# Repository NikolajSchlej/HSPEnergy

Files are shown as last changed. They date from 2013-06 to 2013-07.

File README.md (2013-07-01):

HSP Energy
=========

Hardware project of HS Regensburg

This project of Embedded Systems Laboratory of HS Regensburg 
aims to work out rules and guidelines for energy-effective coding
for different uC families.

There is a base board, where DC-DC, JTAG debugger and USB-UART converter are located, 
and CPU boards for different microcontrollers.

Documentation will be added when ready.

Scematics and layouts made in EagleCAD 6. 
All hardware involved is open and available under terms of copyleft license.

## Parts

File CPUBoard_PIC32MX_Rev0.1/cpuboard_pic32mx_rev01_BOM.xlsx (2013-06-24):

Designator | Quantity | Designator | Value1 | Value2 | Value3 | Package | Description | Manufacturer | Manufacturer # | Farnell # | Digikey # | Unit price € | Total Price €
 | 1 |  |  |  |  | TQFP-100 | Microcontroller | Microchip | PIC32MX320F128L | 1523321 | PIC32MX320F128L-80I/PT | 6.670 | 6.670
 | 1 | C9 | 10uF | 50V | +/- 20% | SMT | Aluminum Electrolytic Capacitor | Panasonic | EEEFK1H100P | 1850117 |  | 0.269 | 0.269
 | 2 |  | 1x24 |  |  |  | pin header male |  |  | 1593425 |  | 0.671 | 1.342
 | 2 | C1,C2 | 22pF |  |  | 0805 | Capacitor |  |  | 1885437 |  | 0.297 | 0.594
 | 7 | C3,C4,C5,C6,C7,C8,C10 | 100nF |  |  | 0805 | Capacitor | Multicomp |  | 1759265 |  | 0.011 | 0.077
DNP | 1 | JP3 |  |  |  |  | Programming connector
 | 1 | JP4 | RJ12 |  |  |  | Programming connector |  |  | 3938359 |  | 1.180 | 1.180
 | 2 | R1,R2 | 10K | 1% |  | 0805 | Resistor |  |  | 1612522 |  | 0.032 | 0.064
 | 2 | S1,S2 |  |  |  |  | tactile switch | ALPS | SKHHBWA010 | 2056816 |  | 0.162 | 0.162

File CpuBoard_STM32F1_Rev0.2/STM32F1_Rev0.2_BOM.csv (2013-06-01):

Part | Value | Device | Package | Description | MPN | OC_FARNELL | OC_NEWARK | PACKAGE | SUPPLIER
C1 | 10nF | C-EUC0805K | C0805K | CAPACITOR, European symbol
C2 | 100nF | C-EUC0805K | C0805K | CAPACITOR, European symbol
C3 | 100nF | C-EUC0805K | C0805K | CAPACITOR, European symbol
C4 | 20pF | C-EUC0805K | C0805K | CAPACITOR, European symbol
C5 | 20pF | C-EUC0805K | C0805K | CAPACITOR, European symbol
C6 | 1uF | CPOL-EUB | PANASONIC_B | POLARIZED CAPACITOR, European symbol
C7 | 100nF | C-EUC0805K | C0805K | CAPACITOR, European symbol
C8 | 100nF | C-EUC0805K | C0805K | CAPACITOR, European symbol
C9 | 100nF | C-EUC0805K | C0805K | CAPACITOR, European symbol
C10 | 100nF | C-EUC0805K | C0805K | CAPACITOR, European symbol
C11 | 10uF | CPOL-EUB | PANASONIC_B | POLARIZED CAPACITOR, European symbol
C12 | 100nF | C-EUC0805K | C0805K | CAPACITOR, European symbol
C13 | 100nF | C-EUC0805K | C0805K | CAPACITOR, European symbol
JP1 |  | PINHD-1X24 | 1X24 | PIN HEADER
JP2 |  | PINHD-2X10 | 2X10 | PIN HEADER
JP3 |  | PINHD-1X24 | 1X24 | PIN HEADER
L1 | 470 Ohm@100MHz | INDUCTOR0805 | 0805 | Inductors
R1 | 10K | R-EU_R0805 | R0805 | RESISTOR, European symbol
R2 | 10K | R-EU_R0805 | R0805 | RESISTOR, European symbol
R3 | 10K | R-EU_R0805 | R0805 | RESISTOR, European symbol
R4 | 10K | R-EU_R0805 | R0805 | RESISTOR, European symbol
R5 | 10K | R-EU_R0805 | R0805 | RESISTOR, European symbol
R6 | 10K | R-EU_R0805 | R0805 | RESISTOR, European symbol
R7_F1 | 0 | R-EU_R0805 | R0805 | RESISTOR, European symbol
R7_F2 | 0 | R-EU_R0805 | R0805 | RESISTOR, European symbol
R8_F1 | 0 | R-EU_R0805 | R0805 | RESISTOR, European symbol
R8_F2 | 0 | R-EU_R0805 | R0805 | RESISTOR, European symbol
R9_F1 | 0 | R-EU_R0805 | R0805 | RESISTOR, European symbol
S1 | SWITCH_TH | SWITCH_TH | SWITCH_TROUGHHOLE
S2 | SWITCH_TH | SWITCH_TH | SWITCH_TROUGHHOLE
S3 | SS12SDXX | SS12SDXX | SS12SDXX
S4 | SS12SDXX | SS12SDXX | SS12SDXX
S5 | SWS004 | SWS004 | SMS-004 | SMD Dip Switch 4 pol.
U$1 | OSHW-LOGOS | OSHW-LOGOS | OSHW-LOGO-S | Open Source Hardware Logo This logo indicates the piece of hardware it is found on incorporates a OSHW license and/or adheres to the definition of open source hardware found here: http://freedomdefined.org/OSHW
U1 | STM32L152VBT6 | STM32L152VBT6 | QFP50P1600X1600X160-100N | Ultralow power ARM-based 32-bit MCU | STM32L152VBT6 | 2060948 | 65T3809 | LQFP-100 | STMICROELECTRONICS
Y1 | 8MHz | CRYSTALSMD | HC49UP | Various standard crystals. Proven footprints. Spark Fun Electronics SKU : COM-00534

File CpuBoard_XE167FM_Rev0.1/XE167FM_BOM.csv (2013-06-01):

Part | Value | Device | Package | Description
C1 | 100nF | CAP0603-CAP | 0603-CAP | Capacitor
C2 | 100nF | CAP0603-CAP | 0603-CAP | Capacitor
C3 | 100nF | CAP0603-CAP | 0603-CAP | Capacitor
C4 | 100nF | CAP0603-CAP | 0603-CAP | Capacitor
C5 | 100nF | CAP0603-CAP | 0603-CAP | Capacitor
C6 | 100nF | CAP0603-CAP | 0603-CAP | Capacitor
C7 | 100nF | CAP0603-CAP | 0603-CAP | Capacitor
C8 | 100nF | CAP0603-CAP | 0603-CAP | Capacitor
C9 | 680nF | CAP0603-CAP | 0603-CAP | Capacitor
C10 | 680nF | CAP0603-CAP | 0603-CAP | Capacitor
C11 | 680nF | CAP0603-CAP | 0603-CAP | Capacitor
C12 | 680nF | CAP0603-CAP | 0603-CAP | Capacitor
C13 | 220nF | CAP0603-CAP | 0603-CAP | Capacitor
C14 | 1.2uF | CAP0603-CAP | 0603-CAP | Capacitor
C15 | 100nF | CAP0603-CAP | 0603-CAP | Capacitor
C16 | 18pF | CAP0603-CAP | 0603-CAP | Capacitor
C17 | 18pF | CAP0603-CAP | 0603-CAP | Capacitor
C18 | 100nF | CAP0603-CAP | 0603-CAP | Capacitor
CONF0 |  | SWITCH-SPDTPTH | SWITCH-SPDT | SPDT Switch
CONF1 |  | SWITCH-SPDTPTH | SWITCH-SPDT | SPDT Switch
CONF2 |  | SWITCH-SPDTPTH | SWITCH-SPDT | SPDT Switch
IC1 | XE167FM | XE167FM | LQFP144 | Infineon XE167FM
JP2 |  | PINHD-1X24 | 1X24 | PIN HEADER
JP3 |  | PINHD-1X24 | 1X24 | PIN HEADER
L1 | 470uH@100Mhz | INDUCTOR0603 | 0603 | Inductors
L2 | 470uH@100Mhz | INDUCTOR0603 | 0603 | Inductors
L3 | 470uH@100Mhz | INDUCTOR0603 | 0603 | Inductors
L4 | 470uH@100Mhz | INDUCTOR0603 | 0603 | Inductors
OCDS |  | PINHD-2X8_2.54 | 2X08 | PIN HEADER
R1 | 10K | RESISTOR0603-RES | 0603-RES | Resistor
R2 | 10K | RESISTOR0603-RES | 0603-RES | Resistor
R3 | 10K | RESISTOR0603-RES | 0603-RES | Resistor
R4 | 10K | RESISTOR0603-RES | 0603-RES | Resistor
R5 | 10K | RESISTOR0603-RES | 0603-RES | Resistor
RESET |  | TAC_SWITCHPTH | TACTILE-PTH | Momentary Switch
TRST |  | SWITCH-SPDTPTH | SWITCH-SPDT | SPDT Switch
VAGND |  | JP1E | JP1 | JUMPER
VAREF |  | JP1E | JP1 | JUMPER
Y1 | 8Mhz | CRYSTALSMD | HC49UP | Various standard crystals. Proven footprints. Spark Fun Electronics SKU : COM-00534

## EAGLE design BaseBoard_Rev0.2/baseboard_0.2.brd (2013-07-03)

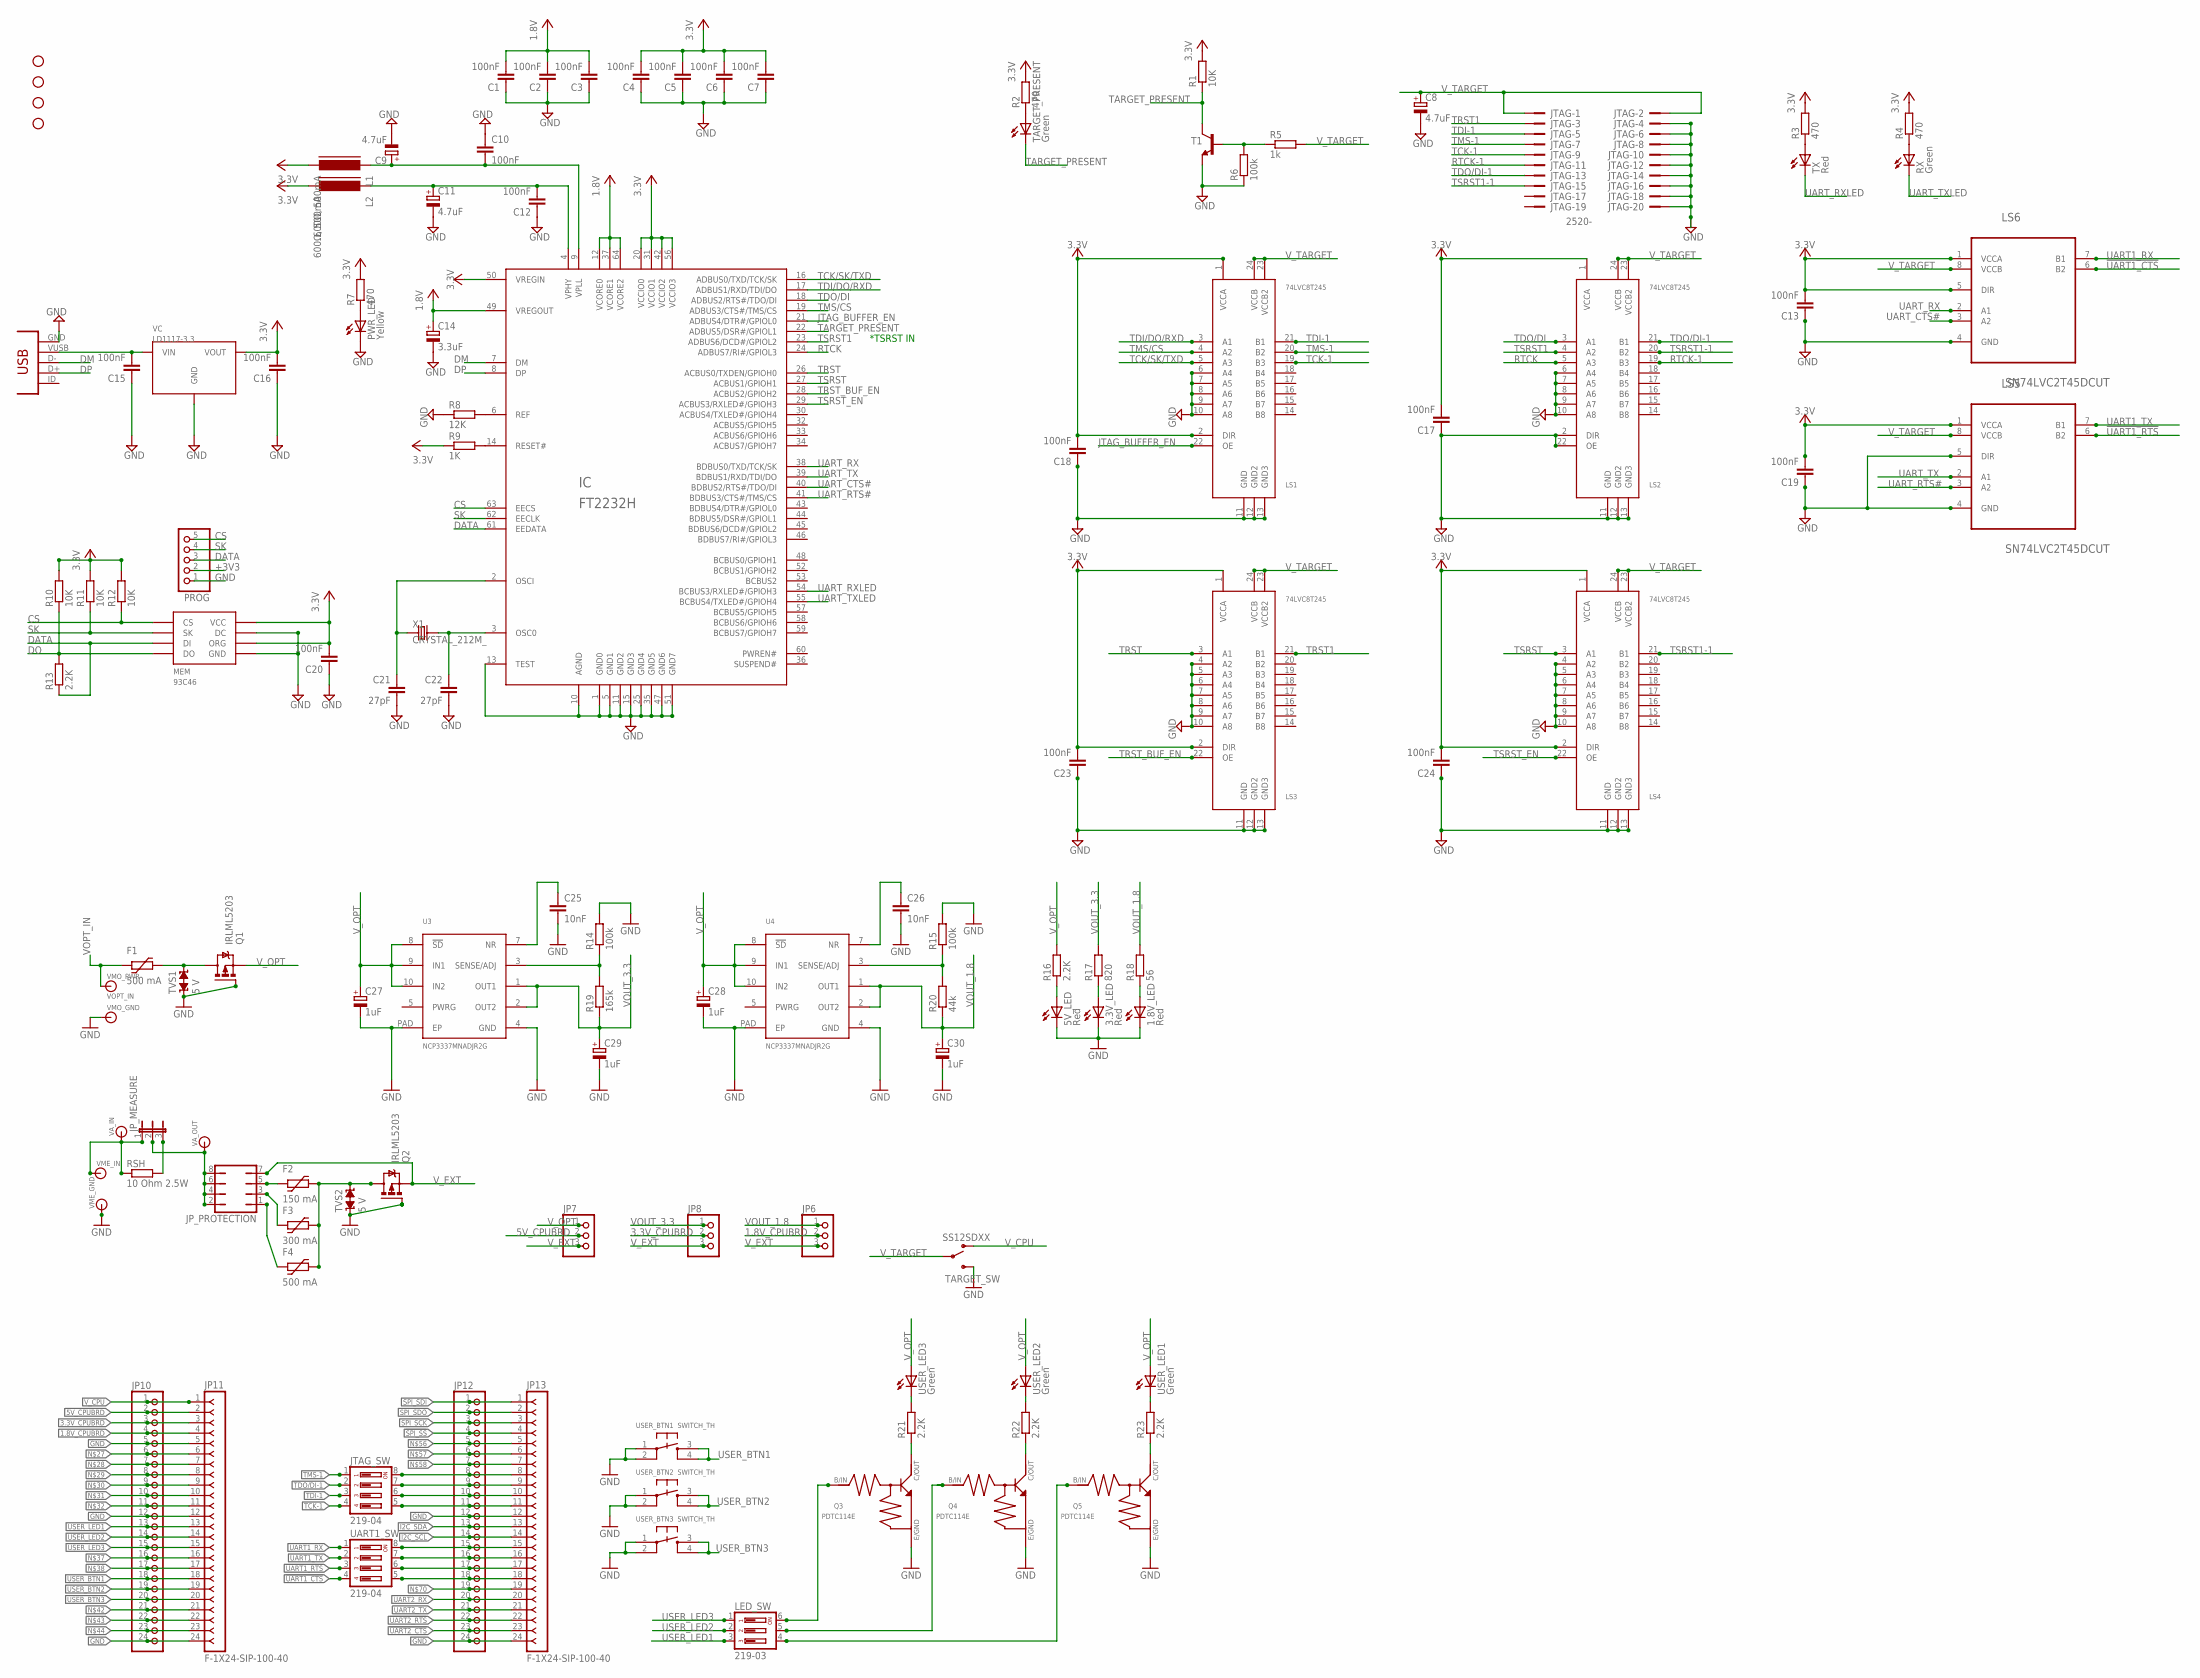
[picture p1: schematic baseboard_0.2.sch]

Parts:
1.8V_LED, 3.3V_LED, 5V_LED: Red; CHIPLED_0805
C1, C2, C3, C4, C5, C6, C7, C10, C12, C13, C15, C16, C17, C18, C19, C20, C23, C24: 100nF; C805
C8, C9, C11: 4.7uF; SMC_A
C14: 3.3uF; SMC_A
C21, C22: 27pF; C805
C25, C26: 10nF; C0805
C27, C28, C29, C30: 1uF; PANASONIC_B
CONN1: CONN_USB; CONN_USB_MINI-B
F1, F4: 500 mA; 1206L
F2: 150 mA; 1206L
F3: 300 mA; 1206L
IC: FT2232H; LQFP64
JP1, JP2, JP3, JP4: STAND-OFF
JP6, JP7, JP8: PINHD-1X3; 1X03
JP10, JP12: PINHD-1X24; 1X24
JP11, JP13: F-1X24-SIP-100-40; SIP-100-24-40
JP_MEASURE: JP2E; JP2
JP_PROTECTION: JP4Q
JTAG: 2520-; PAK100/2500-20
JTAG_SW: 219-04; CTS-219-04
L1, L2: 600Ω, 500mA; FB805
LED_SW: 219-03; CTS-219-03
LS1, LS2, LS3, LS4: 74LVC8T245; TSSOP24
LS5, LS6: SN74LVC2T45DCUT; SOP50P310X90-8N
MEM: 93C46; SOIC8
PROG: PINHD-1X5; 1X05
PWR_LED: Yellow; CHIPLED_0805
Q1, Q2: IRLML5203; MICRO3
Q3, Q4, Q5: PDTC114E; SOT416
R1, R10, R11, R12: 10K; R805
R2, R3, R4, R7: 470; R805
R5: 1k; R805
R6: 100k; R805
R8: 12K; R805
R9: 1K; R805
R13: 2.2K; R805
R14, R15: 100k; R0805
R16, R21, R22, R23: 2.2K; R0805
R17: 820; R0805
R18: 56; R0805
R19: 165k; R0805
R20: 44k; R0805
RSH: 10 Ohm 2.5W; R2512
RX: Green; CHIPLED_0805
T1: NPNSOT23BEC; SOT23-BEC
TARGET_PRESENT: Green; CHIPLED_0805
TARGET_SW: SS12SDXX
TVS1, TVS2: 5 V; TVS0805
TX: Red; CHIPLED_0805
U3, U4: NCP3337MNADJR2G; DFN10
UART1_SW: 219-04; CTS-219-04
USER_BTN1, USER_BTN2, USER_BTN3: SWITCH_TH; SWITCH_TROUGHHOLE
USER_LED1, USER_LED2, USER_LED3: Green; CHIPLED_0805
VA_IN: BANANA_CONN
VA_OUT: BANANA_CONN
VC: LD1117-3.3; SOT223
VME_GND: BANANA_CONN
VME_IN: BANANA_CONN
VMO_GND: BANANA_CONN
VMO_PWR: VOPT_IN; BANANA_CONN
X1: CRYSTAL_212M_; 4X6

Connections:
1.8V: C1.2, C2.2, C3.2, C14.+, IC.12 (VCORE0), IC.37 (VCORE1), IC.49 (VREGOUT), IC.64 (VCORE2)
1.8V_CPUBRD: JP6.2, JP10.4, JP11.4
3.3V_CPUBRD: JP8.2, JP10.3, JP11.3
5V_CPUBRD: JP7.2, JP10.2, JP11.2
!SPI_SS: JP12.4, JP13.4
!UART1_CTS: LS6.6 (B2), UART1_SW.4
!UART1_RTS: LS5.6 (B2), UART1_SW.3
!UART2_CTS: JP12.23, JP13.23
!UART2_RTS: JP12.22, JP13.22
+3V3: C4.2, C5.2, C6.2, C7.2, C13.2, C16.2, C17.2, C18.2, C19.2, C20.2, C23.2, C24.2, IC.20 (VCCIO0), IC.31 (VCCIO1), IC.42 (VCCIO2), IC.50 (VREGIN), IC.56 (VCCIO3), L1.2, L2.2, LS1.1 (VCCA), LS1.2 (DIR), LS2.1 (VCCA), LS3.1 (VCCA), LS3.2 (DIR), LS4.1 (VCCA), LS4.2 (DIR), LS5.1 (VCCA), LS6.1 (VCCA), LS6.5 (DIR), MEM.6 (ORG), MEM.8 (VCC), PROG.2, R1.2, R2.2, R3.2, R4.2, R7.2, R9.1, R10.2, R11.2, R12.2, VC.2 (VOUT)
CS: IC.63 (EECS), MEM.1 (CS), PROG.5, R12.1
DATA: IC.61 (EEDATA), MEM.3 (DI), PROG.3, R13.1
DM: CONN1.D-, IC.7 (DM)
DO: MEM.4 (DO), R10.1, R13.2
DP: CONN1.D+, IC.8 (DP)
GND: 1.8V_LED.C, 3.3V_LED.C, 5V_LED.C, C1.1, C2.1, C3.1, C4.1, C5.1, C6.1, C7.1, C8.-, C9.-, C10.1, C11.-, C12.1, C13.1, C14.-, C15.1, C16.1, C17.1, C18.1, C19.1, C20.1, C21.2, C22.2, C23.1, C24.1, C25.2, C26.2, C27.-, C28.-, C29.-, C30.-, CONN1.GND, IC.1 (GND0), IC.5 (GND1), IC.10 (AGND), IC.11 (GND2), IC.13 (TEST), IC.15 (GND3), IC.25 (GND4), IC.35 (GND5), IC.47 (GND6), IC.51 (GND7), JP10.5, JP10.12, JP10.24, JP11.5, JP11.12, JP11.24, JP12.12, JP12.24, JP13.12, JP13.24, JTAG.4, JTAG.6, JTAG.8, JTAG.10, JTAG.12, JTAG.14, JTAG.16, JTAG.18, JTAG.20, LS1.6 (A4), LS1.7 (A5), LS1.8 (A6), LS1.9 (A7), LS1.10 (A8), LS1.11 (GND), LS1.12 (GND2), LS1.13 (GND3), LS2.2 (DIR), LS2.6 (A4), LS2.7 (A5), LS2.8 (A6), LS2.9 (A7), LS2.10 (A8), LS2.11 (GND), LS2.12 (GND2), LS2.13 (GND3), LS2.22 (OE), LS3.4 (A2), LS3.5 (A3), LS3.6 (A4), LS3.7 (A5), LS3.8 (A6), LS3.9 (A7), LS3.10 (A8), LS3.11 (GND), LS3.12 (GND2), LS3.13 (GND3), LS4.4 (A2), LS4.5 (A3), LS4.6 (A4), LS4.7 (A5), LS4.8 (A6), LS4.9 (A7), LS4.10 (A8), LS4.11 (GND), LS4.12 (GND2), LS4.13 (GND3), LS5.4 (GND), LS5.5 (DIR), LS6.4 (GND), MEM.5 (GND), MEM.7 (DC), PROG.1, PWR_LED.C, Q1.1 (G), Q2.1 (G), Q3.2 (E), Q4.2 (E), Q5.2 (E), R6.1, R8.1, R14.2, R15.2, T1.E, TARGET_SW.3, TVS1.1, TVS2.1, U3.4 (GND), U3.PAD (EP), U4.4 (GND), U4.PAD (EP), USER_BTN1.1, USER_BTN1.2, USER_BTN2.1, USER_BTN2.2, USER_BTN3.1, USER_BTN3.2, VC.1 (GND), VME_GND.P$1, VMO_GND.P$1
I2C_SCL: JP12.14, JP13.14
I2C_SDA: JP12.13, JP13.13
JTAG_BUFFER_EN: IC.21 (ADBUS4/DTR#/GPIOL0), LS1.22 (OE)
JTAG_TCK: JP12.11, JP13.11, JTAG_SW.5
JTAG_TDI: JP12.10, JP13.10, JTAG_SW.6
JTAG_TDO: JP12.9, JP13.9, JTAG_SW.7
JTAG_TMS: JP12.8, JP13.8, JTAG_SW.8
unnamed: LED_SW.6, Q3.1 (B)
unnamed: C22.1, IC.3 (OSC0), X1.2 (X2)
unnamed: F2.P$1 (1), JP_PROTECTION.5
unnamed: F3.P$1 (1), JP_PROTECTION.3
unnamed: F4.P$1 (1), JP_PROTECTION.1
unnamed: F2.P$2 (2), F3.P$2 (2), F4.P$2 (2), Q2.3 (D), TVS2.2
unnamed: C21.1, IC.2 (OSCI), X1.1 (X1)
unnamed: C15.2, CONN1.VUSB, VC.3 (VIN)
unnamed: IC.14 (RESET#), R9.2
unnamed: IC.6 (REF), R8.2
unnamed: 3.3V_LED.A, R17.1
unnamed: R5.1, R6.2, T1.B
unnamed: PWR_LED.A, R7.1
unnamed: R2.1, TARGET_PRESENT.A
unnamed: F1.P$2 (2), Q1.3 (D), TVS1.2
unnamed: 5V_LED.A, R16.1
unnamed: R4.1, RX.A
unnamed: R3.1, TX.A
unnamed: LED_SW.4, Q5.1 (B)
unnamed: 1.8V_LED.A, R18.1
unnamed: JP10.6, JP11.6
unnamed: JP10.7, JP11.7
unnamed: JP10.8, JP11.8
unnamed: JP10.9, JP11.9
unnamed: JP10.10, JP11.10
unnamed: JP10.11, JP11.11
unnamed: JP_MEASURE.1, RSH.1, VA_IN.P$1, VME_IN.P$1
unnamed: JP_MEASURE.3, RSH.2
unnamed: JP10.16, JP11.16
unnamed: JP10.17, JP11.17
unnamed: JP10.21, JP11.21
unnamed: JP10.22, JP11.22
unnamed: JP10.23, JP11.23
unnamed: C25.1, U3.7 (NR)
unnamed: JP12.5, JP13.5
unnamed: JP12.6, JP13.6
unnamed: JP12.7, JP13.7
unnamed: Q3.3 (C), R21.1
unnamed: R21.2, USER_LED3.C
unnamed: R22.2, USER_LED2.C
unnamed: R23.2, USER_LED1.C
unnamed: Q4.3 (C), R22.1
unnamed: JP12.15, JP13.15, UART1_SW.8
unnamed: JP12.16, JP13.16, UART1_SW.7
unnamed: JP12.17, JP13.17, UART1_SW.6
unnamed: JP12.18, JP13.18, UART1_SW.5
unnamed: JP12.19, JP13.19
unnamed: R14.1, R19.2, U3.3 (SENSE/ADJ)
unnamed: Q5.3 (C), R23.1
unnamed: C26.1, U4.7 (NR)
unnamed: LED_SW.5, Q4.1 (B)
unnamed: R15.1, R20.2, U4.3 (SENSE/ADJ)
RTCK: IC.24 (ADBUS7/RI#/GPIOL3), LS2.5 (A3)
RTCK-1: JTAG.11, LS2.19 (B3)
SK: IC.62 (EECLK), MEM.2 (SK), PROG.4, R11.1
SPI_SCK: JP12.3, JP13.3
SPI_SDI: JP12.1, JP13.1
SPI_SDO: JP12.2, JP13.2
TARGET_PRESENT: IC.22 (ADBUS5/DSR#/GPIOL1), R1.1, T1.C, TARGET_PRESENT.C
TCK-1: JTAG.9, JTAG_SW.4, LS1.19 (B3)
TCK/SK/TXD: IC.16 (ADBUS0/TXD/TCK/SK), LS1.5 (A3)
TDI-1: JTAG.5, JTAG_SW.3, LS1.21 (B1)
TDI/DO/RXD: IC.17 (ADBUS1/RXD/TDI/DO), LS1.3 (A1)
TDO/DI: IC.18 (ADBUS2/RTS#/TDO/DI), LS2.3 (A1)
TDO/DI-1: JTAG.13, JTAG_SW.2, LS2.21 (B1)
TMS-1: JTAG.7, JTAG_SW.1, LS1.20 (B2)
TMS/CS: IC.19 (ADBUS3/CTS#/TMS/CS), LS1.4 (A2)
TRST: IC.26 (ACBUS0/TXDEN/GPIOH0), LS3.3 (A1)
TRST1: JTAG.3, LS3.21 (B1)
TRST_BUF_EN: IC.28 (ACBUS2/GPIOH2), LS3.22 (OE)
TSRST: IC.27 (ACBUS1/GPIOH1), LS4.3 (A1)
TSRST1: IC.23 (ADBUS6/DCD#/GPIOL2), LS2.4 (A2)
TSRST1-1: JTAG.15, LS2.20 (B2), LS4.21 (B1)
TSRST_EN: IC.29 (ACBUS3/RXLED#/GPIOH3), LS4.22 (OE)
UART1_RX: LS6.7 (B1), UART1_SW.1
UART1_TX: LS5.7 (B1), UART1_SW.2
UART2_RX: JP12.20, JP13.20
UART2_TX: JP12.21, JP13.21
UART_CTS#: IC.40 (BDBUS2/RTS#/TDO/DI), LS6.3 (A2)
UART_RTS#: IC.41 (BDBUS3/CTS#/TMS/CS), LS5.3 (A2)
UART_RX: IC.38 (BDBUS0/TXD/TCK/SK), LS6.2 (A1)
UART_RXLED: IC.54 (BCBUS3/RXLED#/GPIOH3), TX.C
UART_TX: IC.39 (BDBUS1/RXD/TDI/DO), LS5.2 (A1)
UART_TXLED: IC.55 (BCBUS4/TXLED#/GPIOH4), RX.C
USER_BTN1: JP10.18, JP11.18, USER_BTN1.3, USER_BTN1.4
USER_BTN2: JP10.19, JP11.19, USER_BTN2.3, USER_BTN2.4
USER_BTN3: JP10.20, JP11.20, USER_BTN3.3, USER_BTN3.4
USER_LED1: JP10.13, JP11.13, LED_SW.3
USER_LED2: JP10.14, JP11.14, LED_SW.2
USER_LED3: JP10.15, JP11.15, LED_SW.1
VEXT_IN: JP_MEASURE.2, JP_PROTECTION.2, JP_PROTECTION.4, JP_PROTECTION.6, JP_PROTECTION.8, VA_OUT.P$1
VOPT_IN: F1.P$1 (1), VMO_PWR.P$1
VOUT_1.8: C30.+, JP6.1, R18.2, R20.1, U4.1 (OUT1), U4.2 (OUT2)
VOUT_3.3: C29.+, JP8.1, R17.2, R19.1, U3.1 (OUT1), U3.2 (OUT2)
VPHY: C11.+, C12.2, IC.4 (VPHY), L2.1
VPLL: C9.+, C10.2, IC.9 (VPLL), L1.1
V_CPU: JP10.1, JP11.1, TARGET_SW.1
V_EXT: JP6.3, JP7.3, JP8.3, JP_PROTECTION.7, Q2.2 (S)
V_OPT: C27.+, C28.+, JP7.1, Q1.2 (S), R16.2, U3.8 (!SD), U3.9 (IN1), U3.10 (IN2), U4.8 (!SD), U4.9 (IN1), U4.10 (IN2), USER_LED1.A, USER_LED2.A, USER_LED3.A
V_TARGET: C8.+, JTAG.1, JTAG.2, LS1.23 (VCCB2), LS1.24 (VCCB), LS2.23 (VCCB2), LS2.24 (VCCB), LS3.23 (VCCB2), LS3.24 (VCCB), LS4.23 (VCCB2), LS4.24 (VCCB), LS5.8 (VCCB), LS6.8 (VCCB), R5.2, TARGET_SW.2

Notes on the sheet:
*TSRST IN

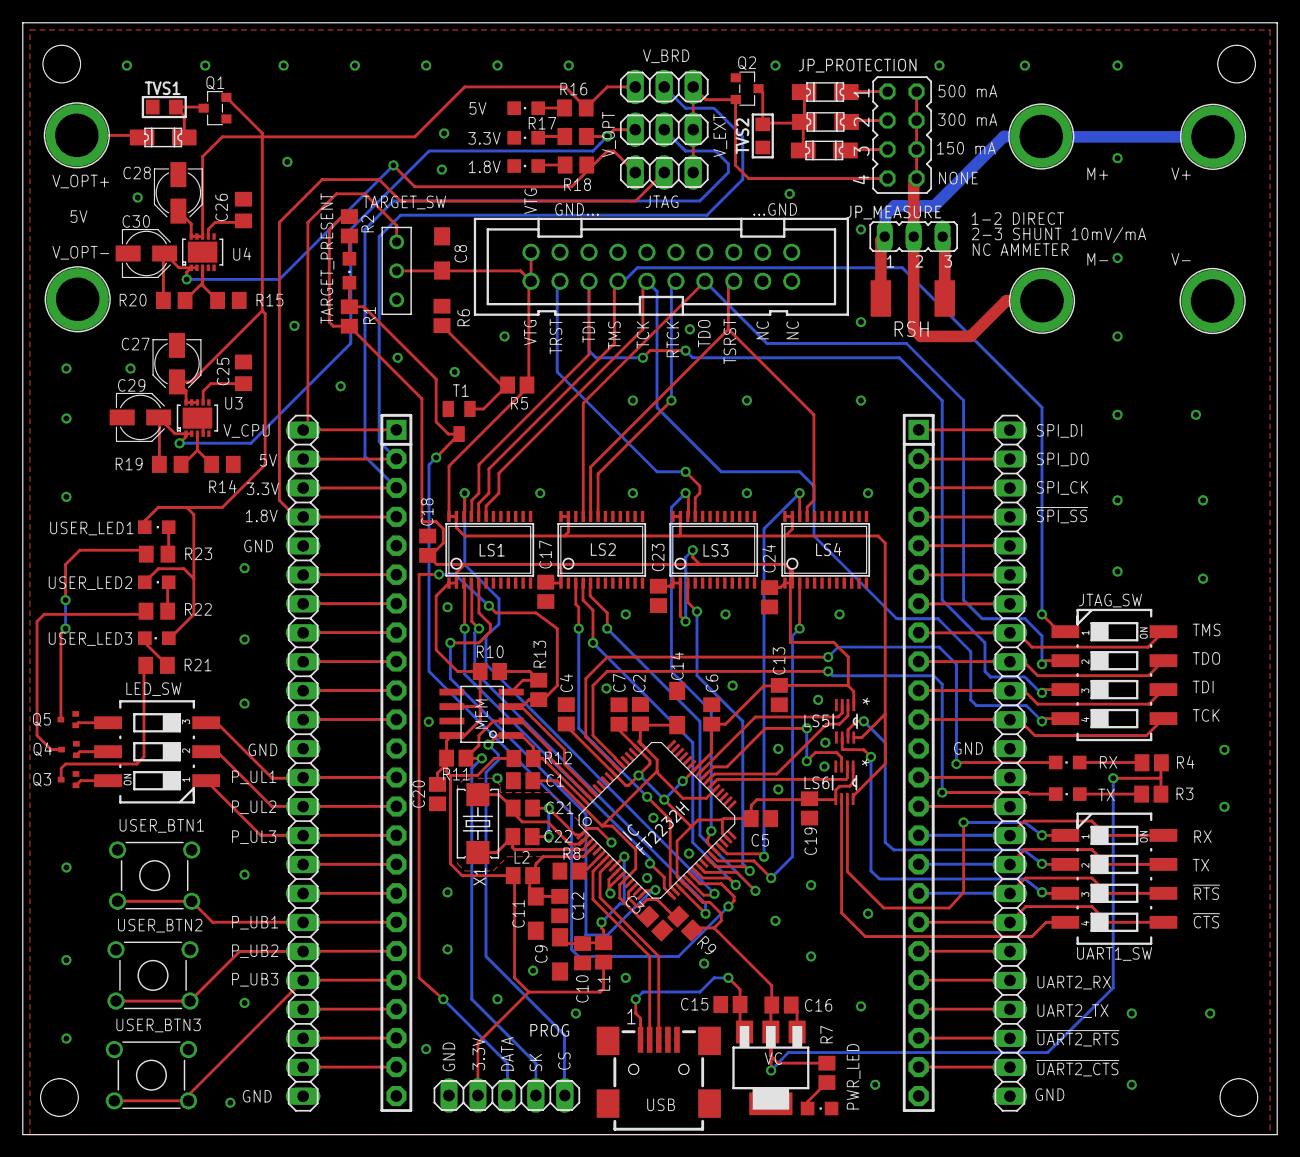
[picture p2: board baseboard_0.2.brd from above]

Board: 2 copper layers, 110.0 x 97.5 mm, 119 parts (0 on the bottom side), 123 nets.

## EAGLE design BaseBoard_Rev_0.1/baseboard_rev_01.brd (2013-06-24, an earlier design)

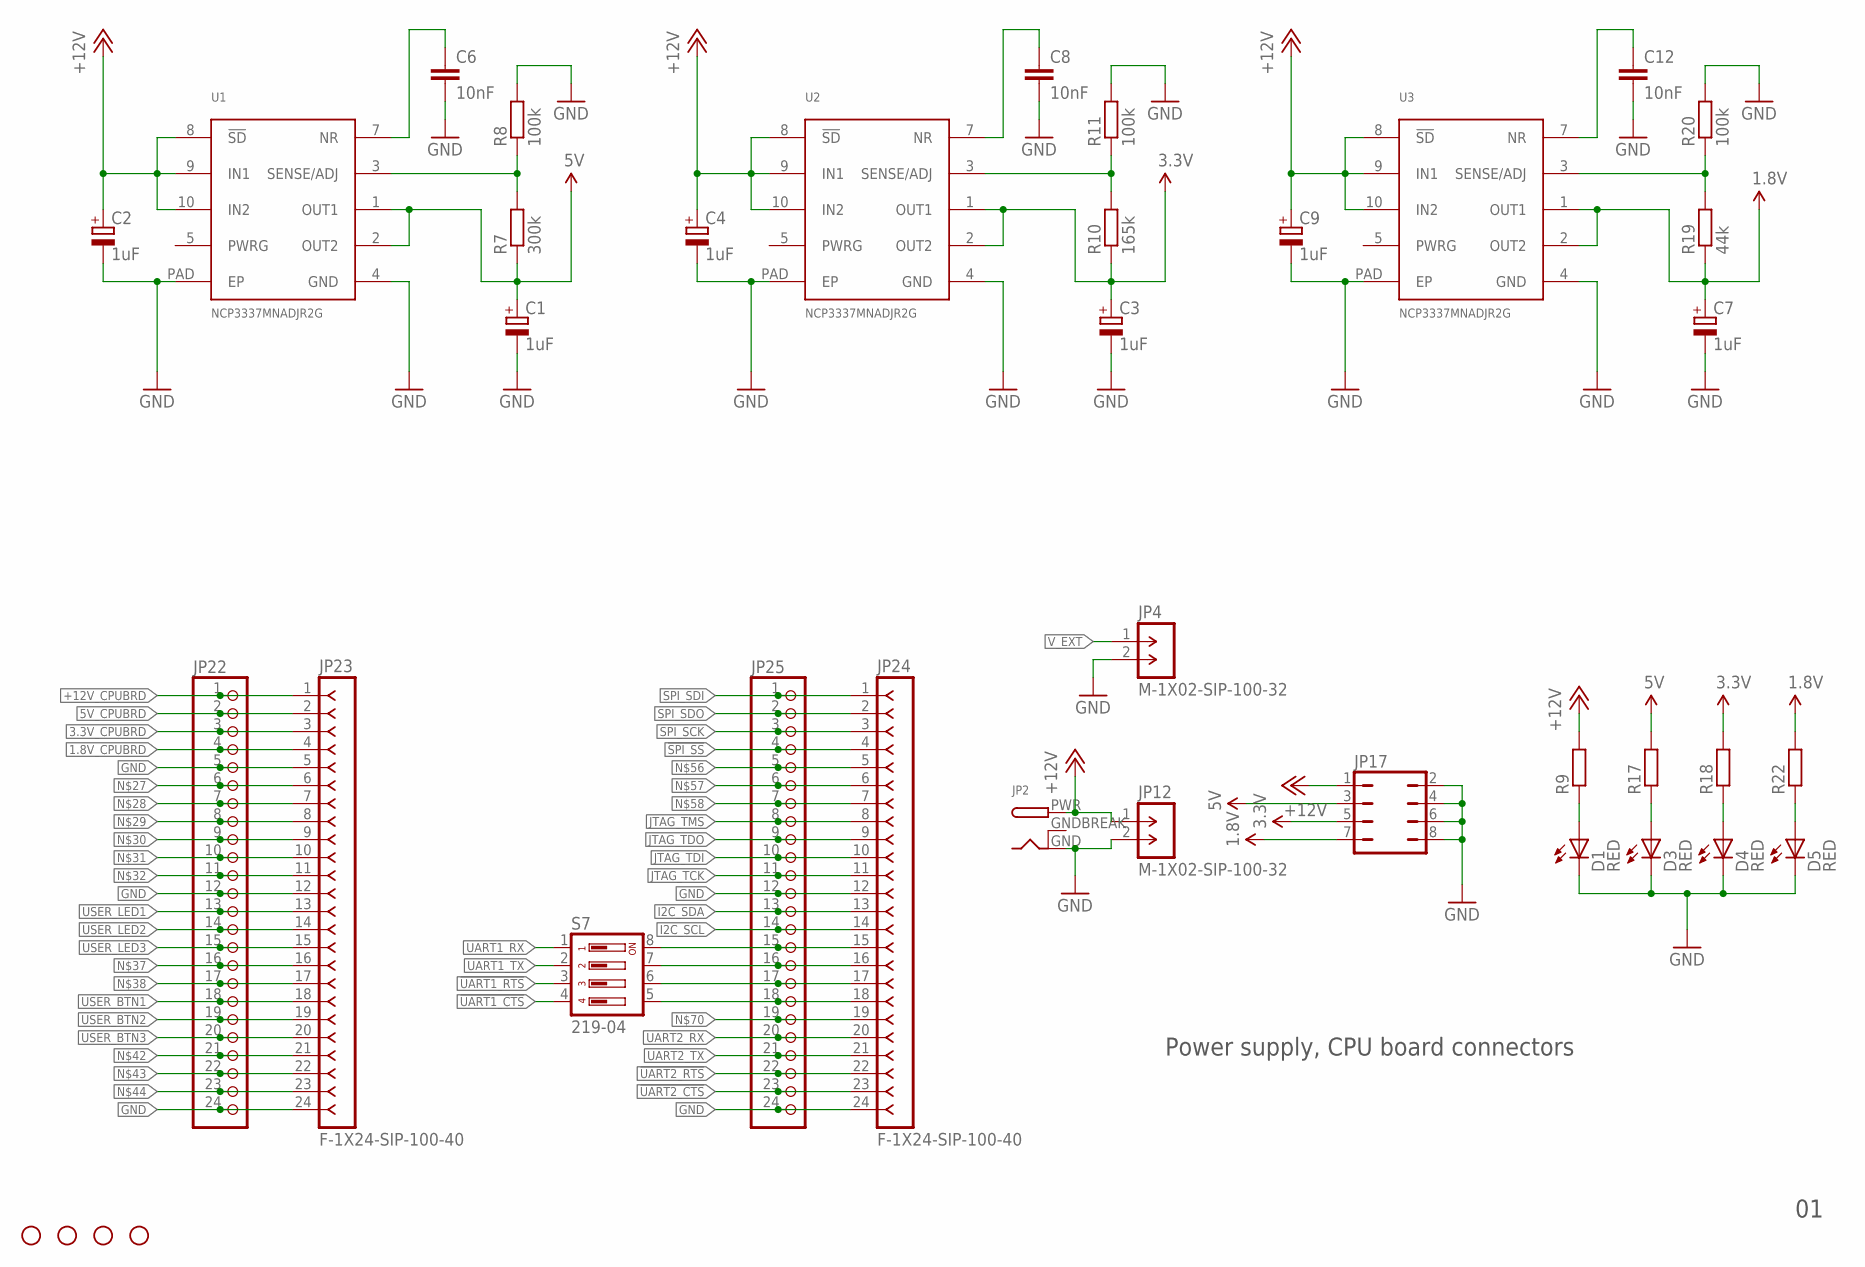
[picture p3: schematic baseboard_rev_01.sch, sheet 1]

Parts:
C1, C2, C3, C4, C7, C9: 1uF; PANASONIC_B
C6, C8, C12: 10nF; C0805
D1, D3, D4, D5: RED; CHIPLED_0805
JP1, JP11, JP26, JP28: STAND-OFF
JP2: DCBARRELPTH; DCJACK_2MM_PTH
JP4, JP12: M-1X02-SIP-100-32; SIP-100-02-32
JP17: JP4Q
JP22, JP25: PINHD-1X24; 1X24
JP23, JP24: F-1X24-SIP-100-40; SIP-100-24-40
R7: 300k; R0805
R8, R11, R20: 100k; R0805
R9, R17, R18, R22: R-EU_R0805; R0805
R10: 165k; R0805
R19: 44k; R0805
S7: 219-04; CTS-219-04
U1, U2, U3: NCP3337MNADJR2G; DFN10

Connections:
1.8V: C7.+, JP17.7, R19.1, R22.2, U3.1 (OUT1), U3.2 (OUT2); also elsewhere on the board
1.8V_CPUBRD: JP22.4, JP23.4; also elsewhere on the board
3.3V: C3.+, JP17.5, R10.1, R18.2, U2.1 (OUT1), U2.2 (OUT2); also elsewhere on the board
3.3V_CPUBRD: JP22.3, JP23.3; also elsewhere on the board
5V: C1.+, JP17.3, R7.1, R17.2, U1.1 (OUT1), U1.2 (OUT2); also elsewhere on the board
5V_CPUBRD: JP22.2, JP23.2; also elsewhere on the board
!SPI_SS: JP24.4, JP25.4
!UART1_CTS: S7.4; also elsewhere on the board
!UART1_RTS: S7.3; also elsewhere on the board
!UART2_CTS: JP24.23, JP25.23
!UART2_RTS: JP24.22, JP25.22
+12V: C2.+, C4.+, C9.+, JP2.PWR, JP12.1, JP17.1, R9.2, U1.8 (!SD), U1.9 (IN1), U1.10 (IN2), U2.8 (!SD), U2.9 (IN1), U2.10 (IN2), U3.8 (!SD), U3.9 (IN1), U3.10 (IN2); also elsewhere on the board
+12V_CPUBRD: JP22.1, JP23.1; also elsewhere on the board
GND: C1.-, C2.-, C3.-, C4.-, C6.2, C7.-, C8.2, C9.-, C12.2, D1.C, D3.C, D4.C, D5.C, JP2.GND, JP4.2, JP12.2, JP17.2, JP17.4, JP17.6, JP17.8, JP22.5, JP22.12, JP22.24, JP23.5, JP23.12, JP23.24, JP24.12, JP24.24, JP25.12, JP25.24, R8.2, R11.2, R20.2, U1.4 (GND), U1.PAD (EP), U2.4 (GND), U2.PAD (EP), U3.4 (GND), U3.PAD (EP); also elsewhere on the board
GNDBREAK: JP2.GNDBREAK
I2C_SCL: JP24.14, JP25.14
I2C_SDA: JP24.13, JP25.13
JTAG_TCK: JP24.11, JP25.11
JTAG_TDI: JP24.10, JP25.10
JTAG_TDO: JP24.9, JP25.9
JTAG_TMS: JP24.8, JP25.8
unnamed: D4.A, R18.1
unnamed: D3.A, R17.1
unnamed: D1.A, R9.1
unnamed: D5.A, R22.1
unnamed: JP22.6, JP23.6
unnamed: JP22.7, JP23.7
unnamed: JP22.8, JP23.8
unnamed: JP22.9, JP23.9
unnamed: JP22.10, JP23.10
unnamed: JP22.11, JP23.11
unnamed: JP22.16, JP23.16
unnamed: JP22.17, JP23.17
unnamed: JP22.21, JP23.21
unnamed: JP22.22, JP23.22
unnamed: JP22.23, JP23.23
unnamed: C8.1, U2.7 (NR)
unnamed: JP24.5, JP25.5
unnamed: JP24.6, JP25.6
unnamed: JP24.7, JP25.7
unnamed: JP24.15, JP25.15, S7.8
unnamed: JP24.16, JP25.16, S7.7
unnamed: JP24.17, JP25.17, S7.6
unnamed: JP24.18, JP25.18, S7.5
unnamed: JP24.19, JP25.19
unnamed: R10.2, R11.1, U2.3 (SENSE/ADJ)
unnamed: C6.1, U1.7 (NR)
unnamed: R7.2, R8.1, U1.3 (SENSE/ADJ)
unnamed: C12.1, U3.7 (NR)
unnamed: R19.2, R20.1, U3.3 (SENSE/ADJ)
SPI_SCK: JP24.3, JP25.3
SPI_SDI: JP24.1, JP25.1
SPI_SDO: JP24.2, JP25.2
UART1_RX: S7.1; also elsewhere on the board
UART1_TX: S7.2; also elsewhere on the board
UART2_RX: JP24.20, JP25.20
UART2_TX: JP24.21, JP25.21
USER_BTN1: JP22.18, JP23.18; also elsewhere on the board
USER_BTN2: JP22.19, JP23.19; also elsewhere on the board
USER_BTN3: JP22.20, JP23.20; also elsewhere on the board
USER_LED1: JP22.13, JP23.13; also elsewhere on the board
USER_LED2: JP22.14, JP23.14; also elsewhere on the board
USER_LED3: JP22.15, JP23.15; also elsewhere on the board
V_EXT: JP4.1; also elsewhere on the board

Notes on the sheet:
Power supply, CPU board connectors

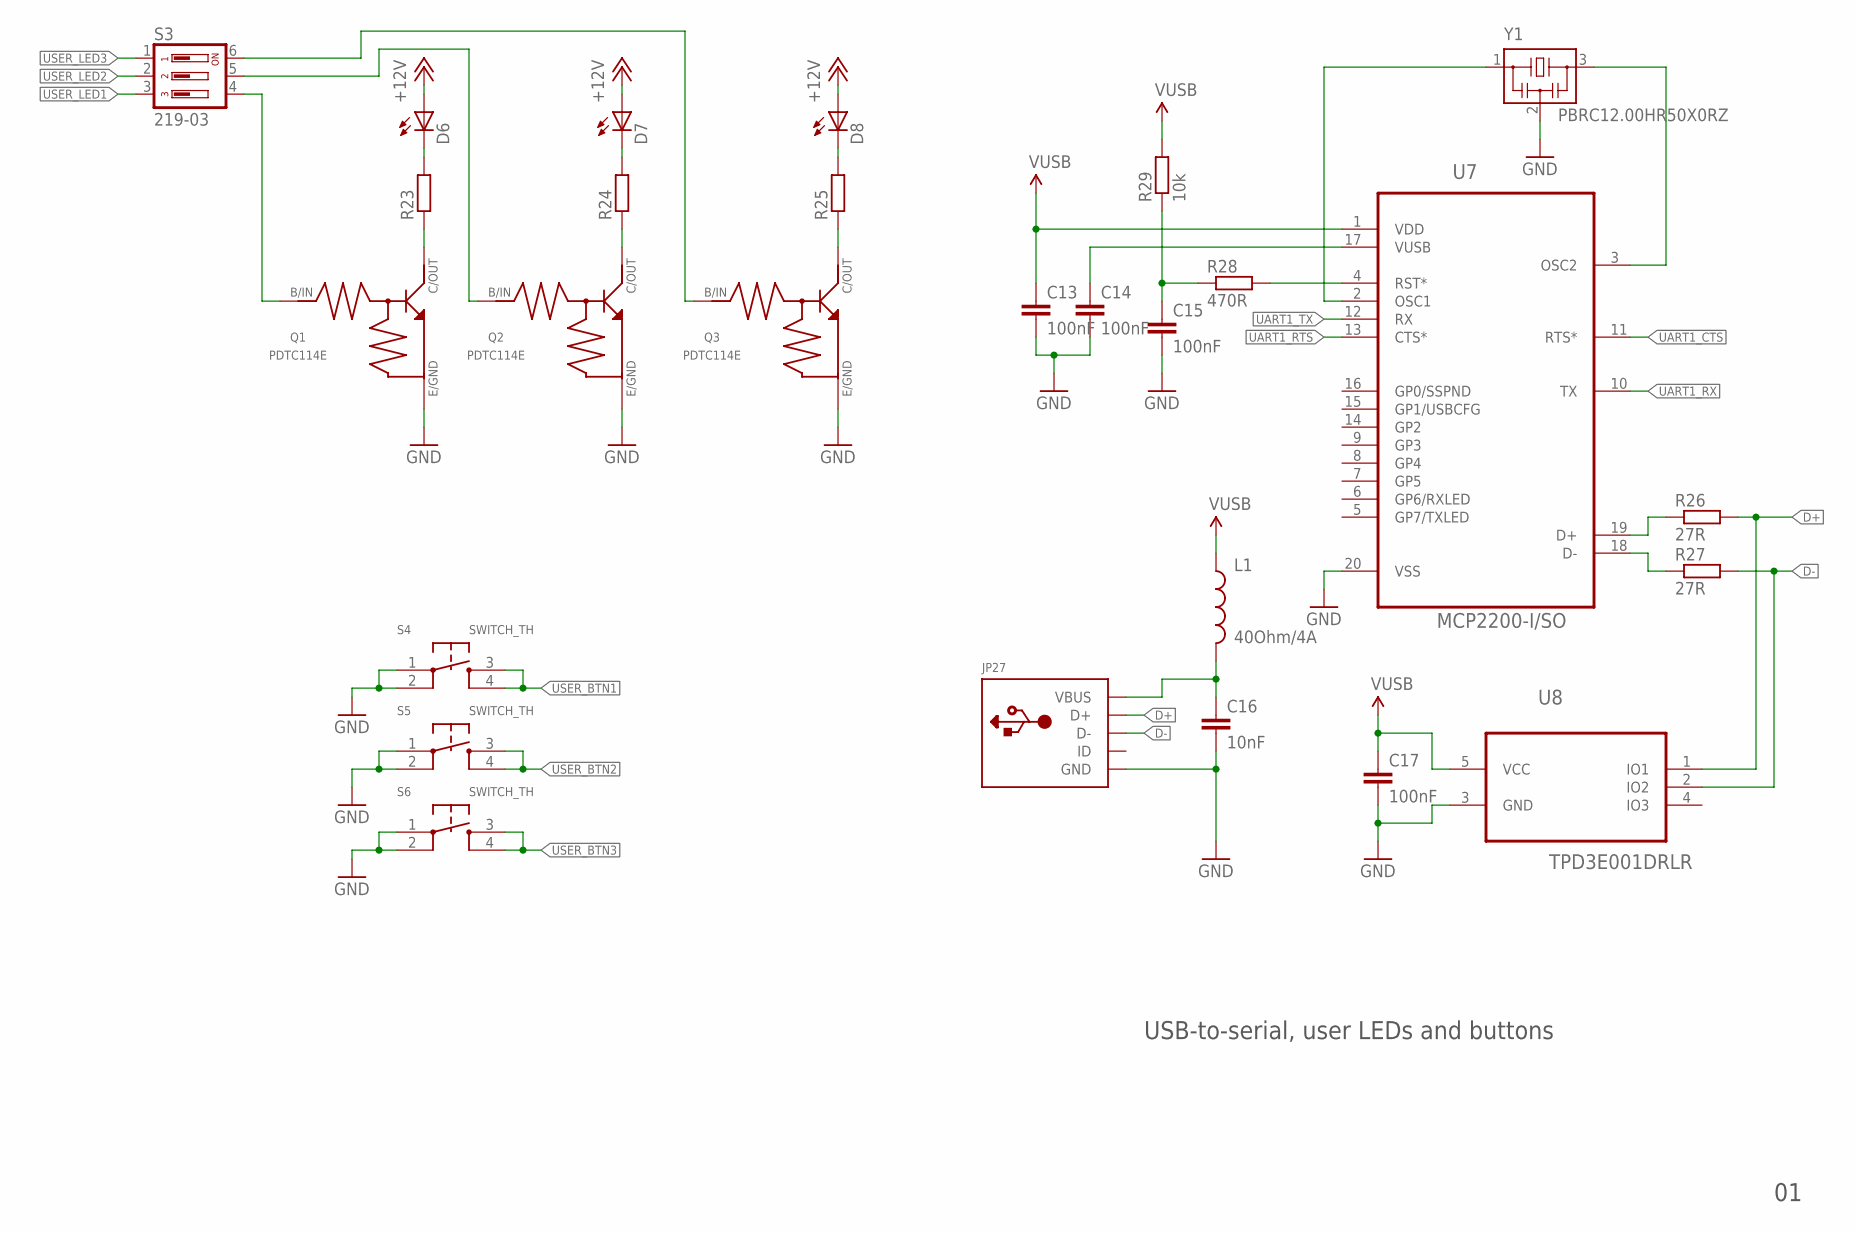
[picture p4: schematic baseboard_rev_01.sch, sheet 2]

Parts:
C13, C14, C15, C17: 100nF; C0805
C16: 10nF; C0805
D6, D7, D8: LEDCHIPLED_0805; CHIPLED_0805
JP27: USBMINIB; USB-MINIB
L1: 40Ohm/4A; 0805
Q1, Q2, Q3: PDTC114E; SOT416
R23, R24, R25: R-EU_R0805; R0805
R26, R27: 27R; R0805
R28: 470R; R0805
R29: 10k; R0805
S3: 219-03; CTS-219-03
S4, S5, S6: SWITCH_TH; SWITCH_TROUGHHOLE
U7: MCP2200-I/SO; SOIC127P1034X264-20N
U8: TPD3E001DRLR; SOT50P160X60-5N
Y1: PBRC12.00HR50X0RZ; PBRC-H

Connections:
!UART1_CTS: U7.11 (RTS*); also elsewhere on the board
!UART1_RTS: U7.13 (CTS*); also elsewhere on the board
+12V: D6.A, D7.A, D8.A; also elsewhere on the board
D+: JP27.D+, R26.2, U8.1 (IO1)
D-: JP27.D-, R27.2, U8.2 (IO2)
GND: C13.2, C14.2, C15.2, C16.2, C17.2, JP27.GND, Q1.2 (E), Q2.2 (E), Q3.2 (E), S4.1, S4.2, S5.1, S5.2, S6.1, S6.2, U7.20 (VSS), U8.3 (GND), Y1.2; also elsewhere on the board
unnamed: Q3.1 (B), S3.6
unnamed: Q2.1 (B), S3.5
unnamed: Q1.1 (B), S3.4
unnamed: Q1.3 (C), R23.1
unnamed: D6.C, R23.2
unnamed: D7.C, R24.2
unnamed: D8.C, R25.2
unnamed: Q2.3 (C), R24.1
unnamed: Q3.3 (C), R25.1
unnamed: C16.1, JP27.VBUS, L1.2
unnamed: C15.1, R28.1, R29.1
unnamed: R28.2, U7.4 (RST*)
unnamed: U7.2 (OSC1), Y1.1
unnamed: C14.1, U7.17 (VUSB)
unnamed: U7.3 (OSC2), Y1.3
unnamed: R26.1, U7.19 (D+)
unnamed: R27.1, U7.18 (D-)
UART1_RX: U7.10 (TX); also elsewhere on the board
UART1_TX: U7.12 (RX); also elsewhere on the board
USER_BTN1: S4.3, S4.4; also elsewhere on the board
USER_BTN2: S5.3, S5.4; also elsewhere on the board
USER_BTN3: S6.3, S6.4; also elsewhere on the board
USER_LED1: S3.3; also elsewhere on the board
USER_LED2: S3.2; also elsewhere on the board
USER_LED3: S3.1; also elsewhere on the board
VUSB: C13.1, C17.1, L1.1, R29.2, U7.1 (VDD), U8.5 (VCC)

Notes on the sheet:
USB-to-serial, user LEDs and buttons

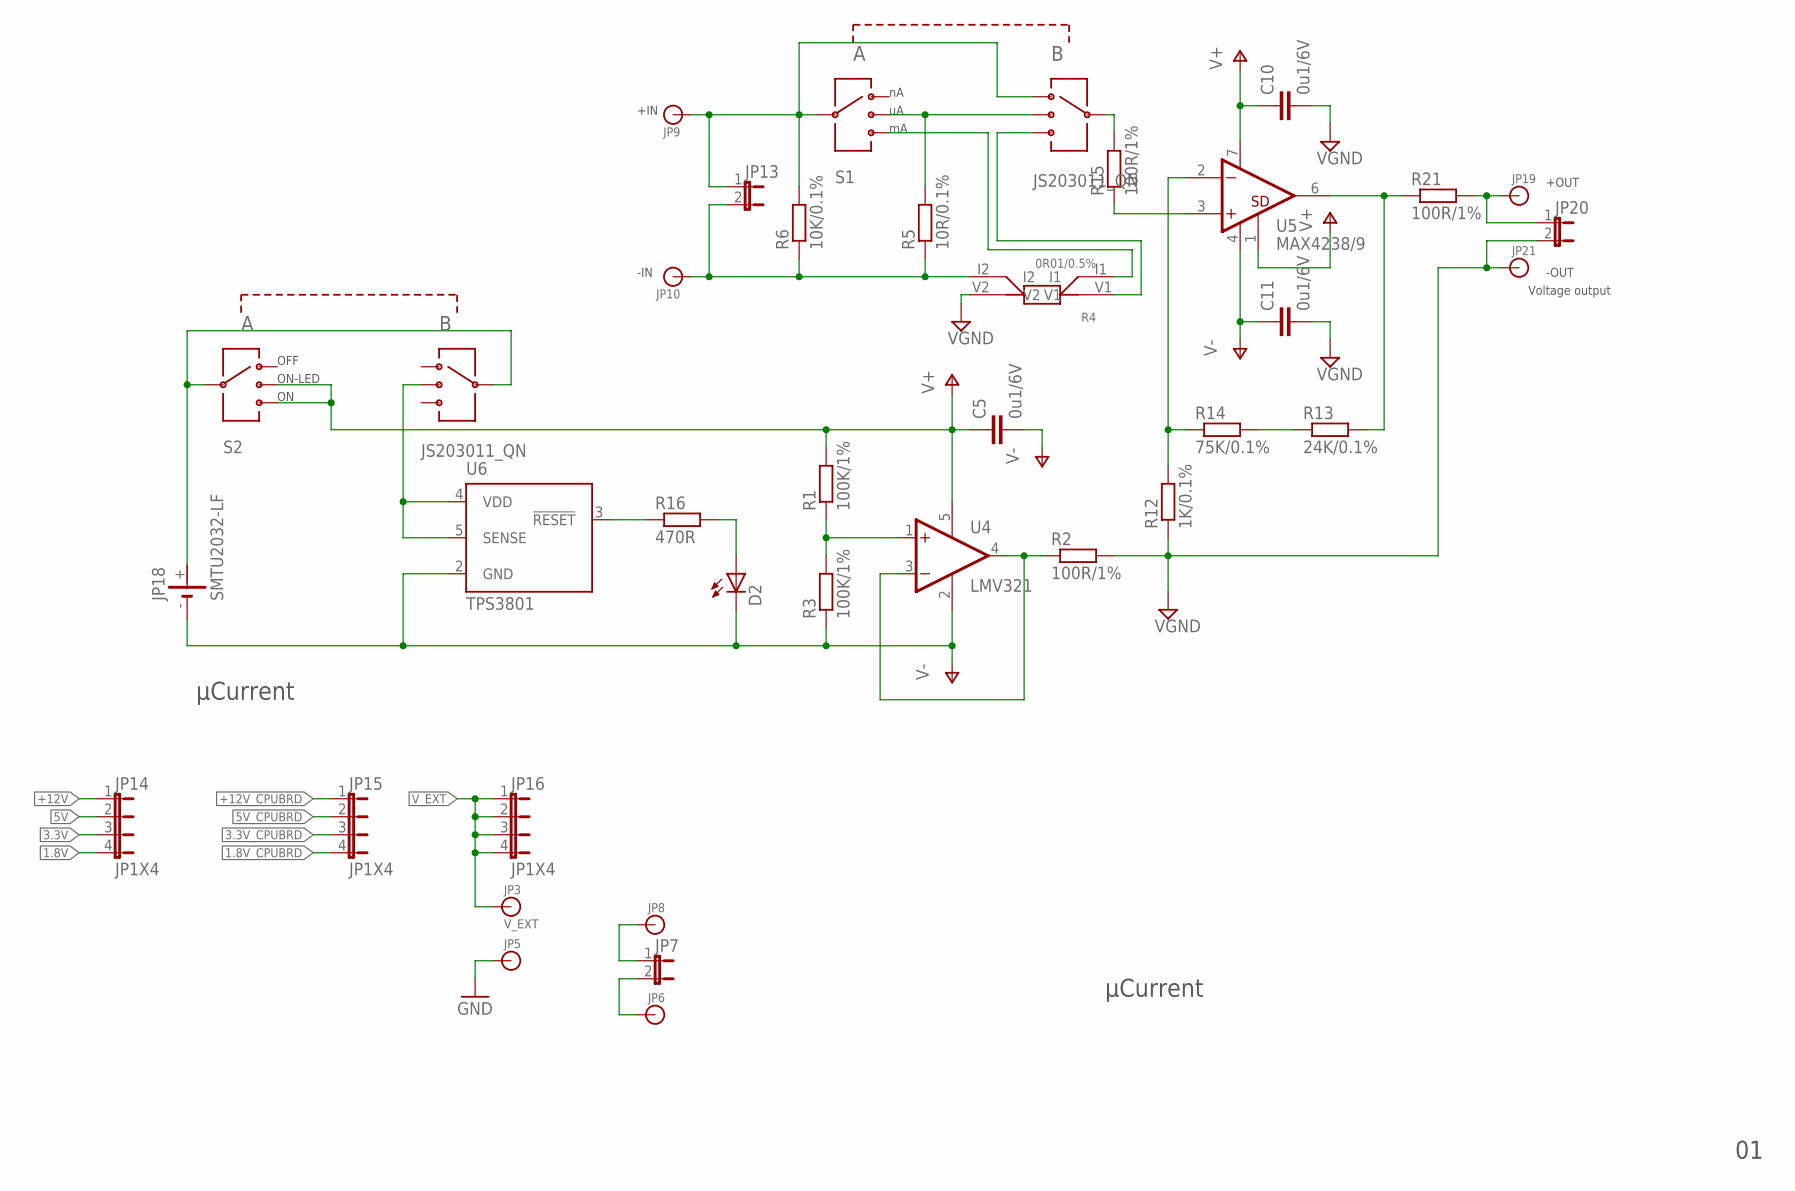
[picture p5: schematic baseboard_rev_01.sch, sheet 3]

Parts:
C5, C10, C11: 0u1/6V; C0805K
D2: LEDCHIPLED_0805; CHIPLED_0805
JP3: V_EXT; BANANA_CONN
JP5, JP6, JP8, JP9, JP10, JP19, JP21: BANANA_CONN
JP7, JP13, JP20: JUMPER-2PTH; 1X02
JP14, JP15, JP16: JP1X4
JP18: SMTU2032-LF
R1, R3: 100K/1%; R0805
R2, R15, R21: 100R/1%; R0805
R4: 0R01/0.5%; LVK12RXXXXXX
R5: 10R/0.1%; R0805
R6: 10K/0.1%; R0805
R12: 1K/0.1%; R0805
R13: 24K/0.1%; R0805
R14: 75K/0.1%; R0805
R16: 470R; R0805
S1, S2: JS203011_QN; JS203011
U4: LMV321; SC70-5L
U5: MAX4238/9; SO08
U6: TPS3801; DCK

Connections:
1.8V: JP14.4; also elsewhere on the board
1.8V_CPUBRD: JP15.4; also elsewhere on the board
3.3V: JP14.3; also elsewhere on the board
3.3V_CPUBRD: JP15.3; also elsewhere on the board
5V: JP14.2; also elsewhere on the board
5V_CPUBRD: JP15.2; also elsewhere on the board
+12V: JP14.1; also elsewhere on the board
+12V_CPUBRD: JP15.1; also elsewhere on the board
CURR_INPUT+: JP9.P$1, JP13.1, R6.2, S1.3, S1.5
GND: JP5.P$1; also elsewhere on the board
unnamed: R15.2, S1.7
unnamed: R15.1, U5.3 (+IN)
unnamed: R12.2, R14.1, U5.2 (-IN)
unnamed: R5.2, S1.2, S1.6
unnamed: R13.1, R14.2
unnamed: R4.I1, S1.4
unnamed: R13.2, R21.1, U5.6 (OUT)
unnamed: JP19.P$1, JP20.1, R21.2
unnamed: JP7.1, JP8.P$1
unnamed: JP6.P$1, JP7.2
unnamed: R2.1, U4.3 (-IN), U4.4 (OUT)
unnamed: R1.1, R3.2, U4.1 (+IN)
unnamed: R16.1, U6.3 (!RESET)
unnamed: S2.6, U6.4 (VDD), U6.5 (SENSE)
unnamed: D2.A, R16.2
unnamed: JP18.+, S2.3, S2.7
unnamed: JP10.P$1, JP13.2, R4.I2, R5.1, R6.1
unnamed: R4.V1, S1.8
V+: C5.1, C10.1, R1.2, S2.2, S2.4, U4.5 (V+), U5.1 (!SHUTDOWN), U5.7 (V+)
V-: C5.2, C11.1, D2.C, JP18.-, R3.1, U4.2 (V-), U5.4 (V-), U6.2 (GND)
VGND: C10.2, C11.2, JP20.2, JP21.P$1, R2.2, R4.V2, R12.1
V_EXT: JP3.P$1, JP16.1, JP16.2, JP16.3, JP16.4; also elsewhere on the board

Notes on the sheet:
+IN
-IN
Voltage output
µCurrent
OFF
ON-LED
+OUT
-OUT

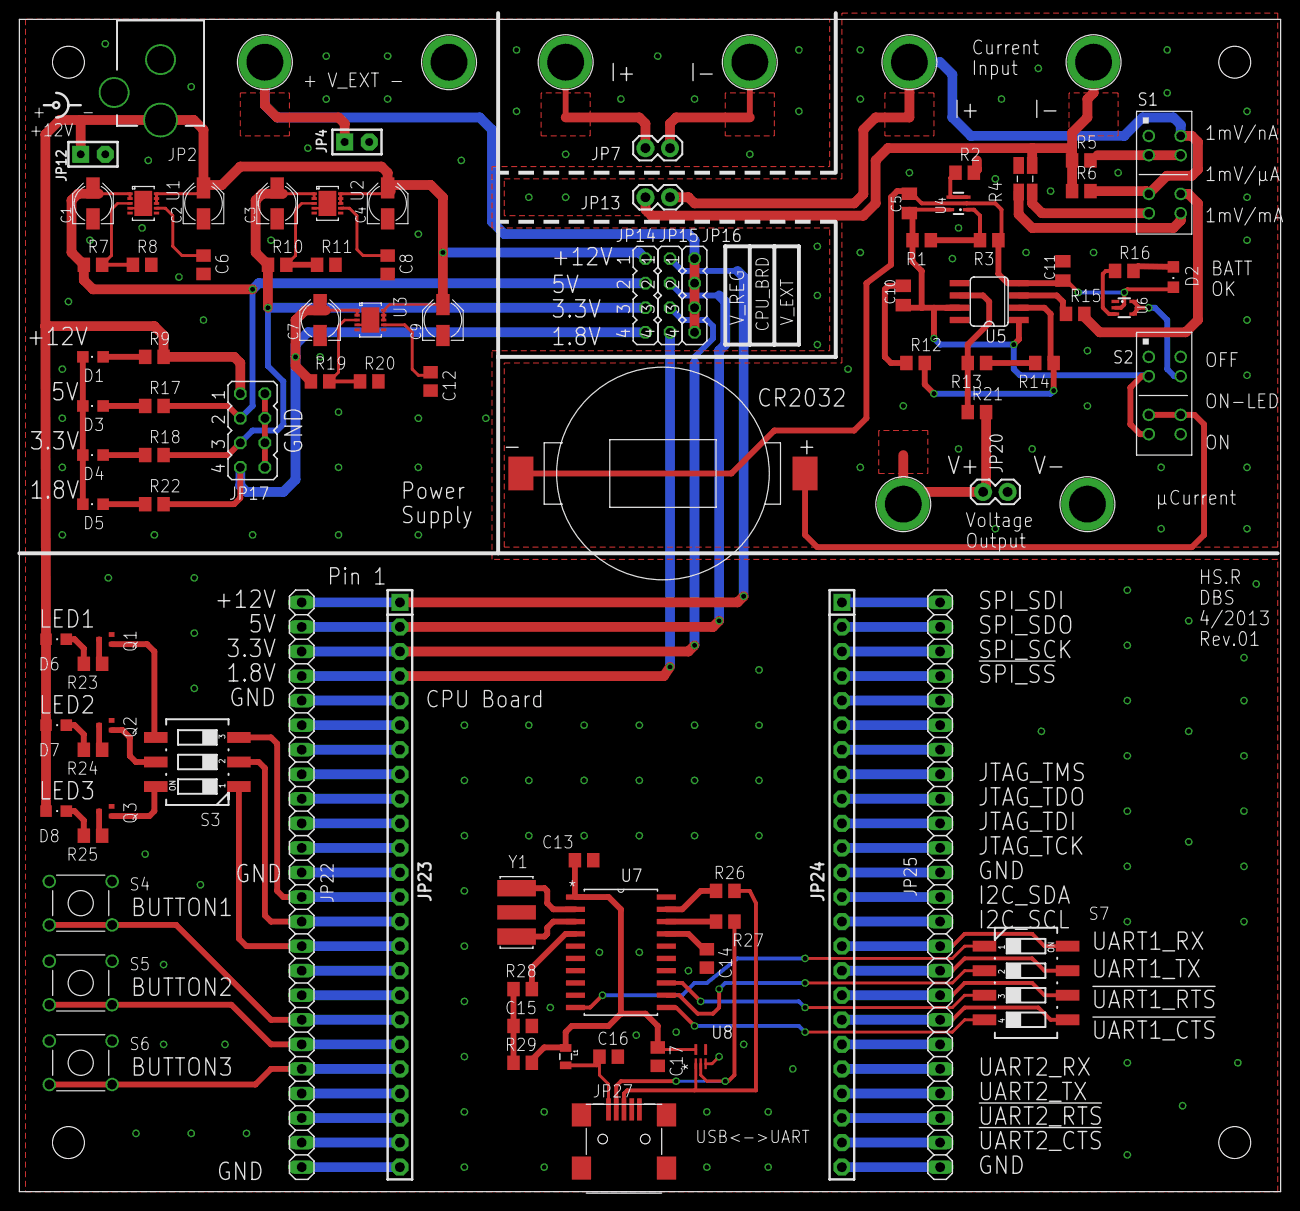
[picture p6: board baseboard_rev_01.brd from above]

Board: 2 copper layers, 130.5 x 121.3 mm, 102 parts (0 on the bottom side), 105 nets.

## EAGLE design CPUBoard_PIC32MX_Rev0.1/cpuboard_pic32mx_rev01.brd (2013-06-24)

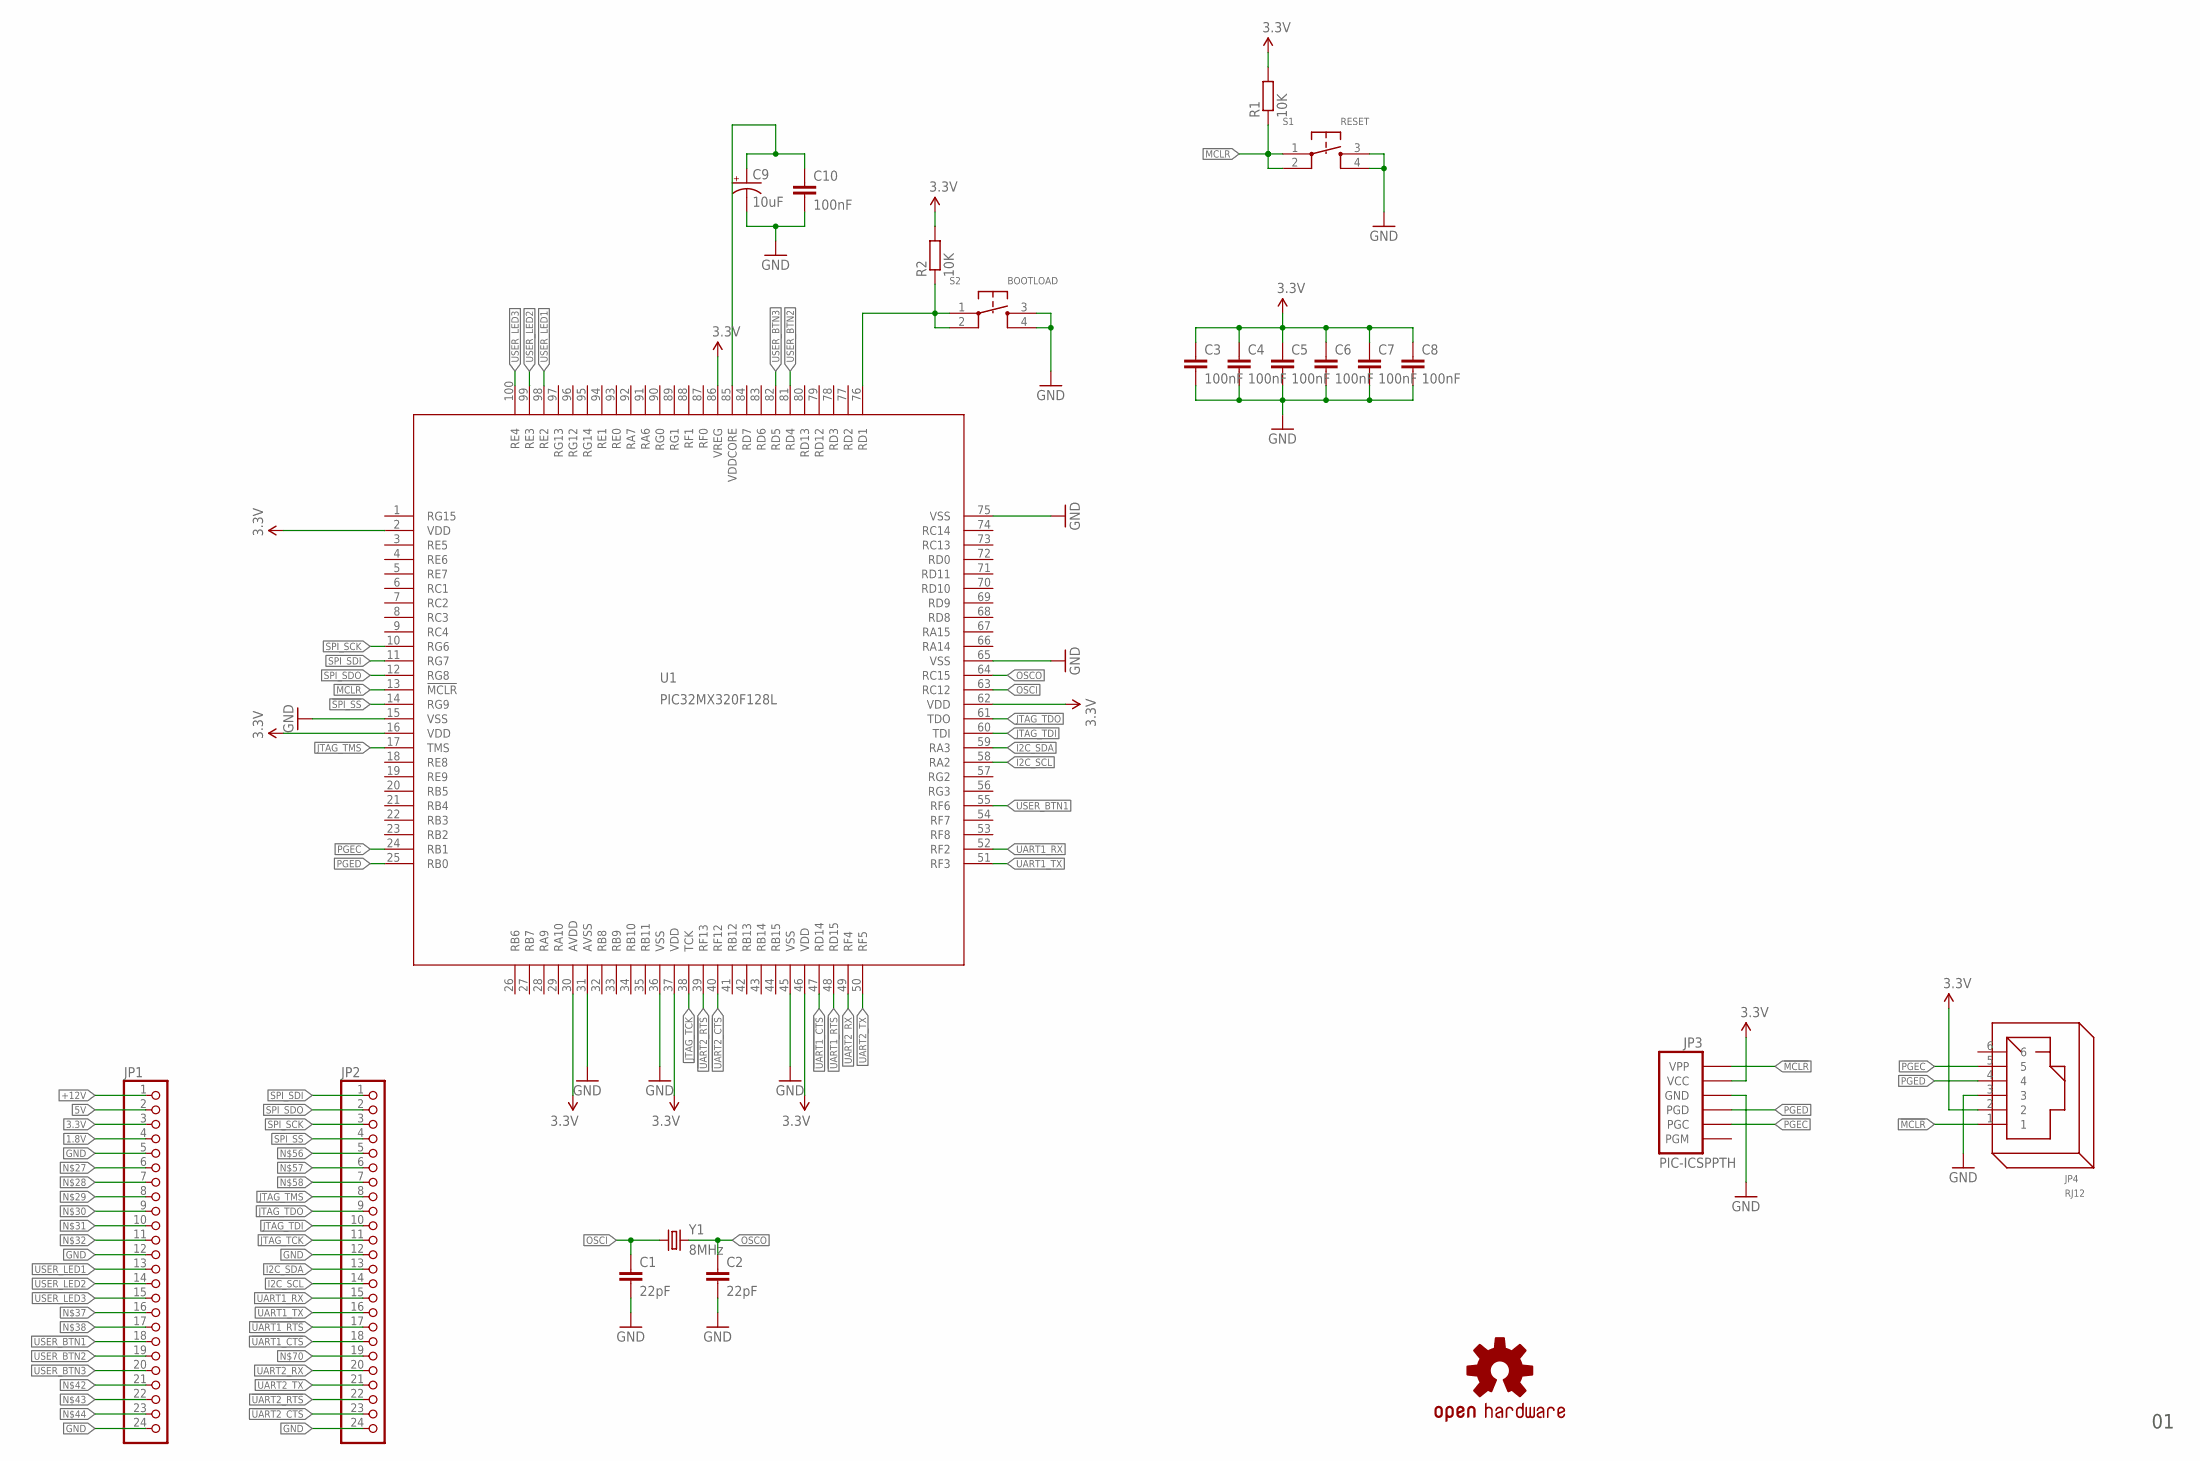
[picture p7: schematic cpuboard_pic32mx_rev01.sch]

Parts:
C1, C2: 22pF; C0805K
C3, C4, C5, C6, C7, C8, C10: 100nF; C0805K
C9: 10uF; PANASONIC_D
JP1, JP2: PINHD-1X24; 1X24
JP3: PIC-ICSPPTH; MOLEX-1X6
JP4: RJ12
R1, R2: 10K; R0805
S1: RESET; SWITCH_TROUGHHOLE
S2: BOOTLOAD; SWITCH_TROUGHHOLE
U1: PIC32MX320F128L; SQFP-S-12X12-100
U$1: OSHW-LOGOS; OSHW-LOGO-S
Y1: 8MHz; HC49UP

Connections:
1.8V: JP1.4
3.3V: C3.1, C4.1, C5.1, C6.1, C7.1, C8.1, JP1.3, JP3.5 (VCC), JP4.2, R1.2, R2.2, U1.2 (VDD), U1.16 (VDD), U1.30 (AVDD), U1.37 (VDD), U1.46 (VDD), U1.62 (VDD), U1.86 (VREG)
5V: JP1.2
!MCLR: JP3.6 (VPP), JP4.1, R1.1, S1.1, S1.2, U1.13 (!MCLR)
!SPI_SS: JP2.4, U1.14 (RG9)
!UART1_CTS: JP2.18, U1.47 (RD14)
!UART1_RTS: JP2.17, U1.48 (RD15)
!UART2_CTS: JP2.23, U1.40 (RF12)
!UART2_RTS: JP2.22, U1.39 (RF13)
+12V: JP1.1
GND: C1.2, C2.2, C3.2, C4.2, C5.2, C6.2, C7.2, C8.2, C9.-, C10.2, JP1.5, JP1.12, JP1.24, JP2.12, JP2.24, JP3.4 (GND), JP4.3, S1.3, S1.4, S2.3, S2.4, U1.15 (VSS), U1.31 (AVSS), U1.36 (VSS), U1.45 (VSS), U1.65 (VSS), U1.75 (VSS)
I2C_SCL: JP2.14, U1.58 (RA2)
I2C_SDA: JP2.13, U1.59 (RA3)
JTAG_TCK: JP2.11, U1.38 (TCK)
JTAG_TDI: JP2.10, U1.60 (TDI)
JTAG_TDO: JP2.9, U1.61 (TDO)
JTAG_TMS: JP2.8, U1.17 (TMS)
unnamed: C9.+, C10.1, U1.85 (VDDCORE)
unnamed: R2.1, S2.1, S2.2, U1.76 (RD1)
OSCI: C1.1, U1.63 (RC12), Y1.1
OSCO: C2.1, U1.64 (RC15), Y1.2
PGEC: JP3.2 (PGC), JP4.5, U1.24 (RB1)
PGED: JP3.3 (PGD), JP4.4, U1.25 (RB0)
SPI_SCK: JP2.3, U1.10 (RG6)
SPI_SDI: JP2.1, U1.11 (RG7)
SPI_SDO: JP2.2, U1.12 (RG8)
UART1_RX: JP2.15, U1.52 (RF2)
UART1_TX: JP2.16, U1.51 (RF3)
UART2_RX: JP2.20, U1.49 (RF4)
UART2_TX: JP2.21, U1.50 (RF5)
USER_BTN1: JP1.18, U1.55 (RF6)
USER_BTN2: JP1.19, U1.81 (RD4)
USER_BTN3: JP1.20, U1.82 (RD5)
USER_LED1: JP1.13, U1.98 (RE2)
USER_LED2: JP1.14, U1.99 (RE3)
USER_LED3: JP1.15, U1.100 (RE4)

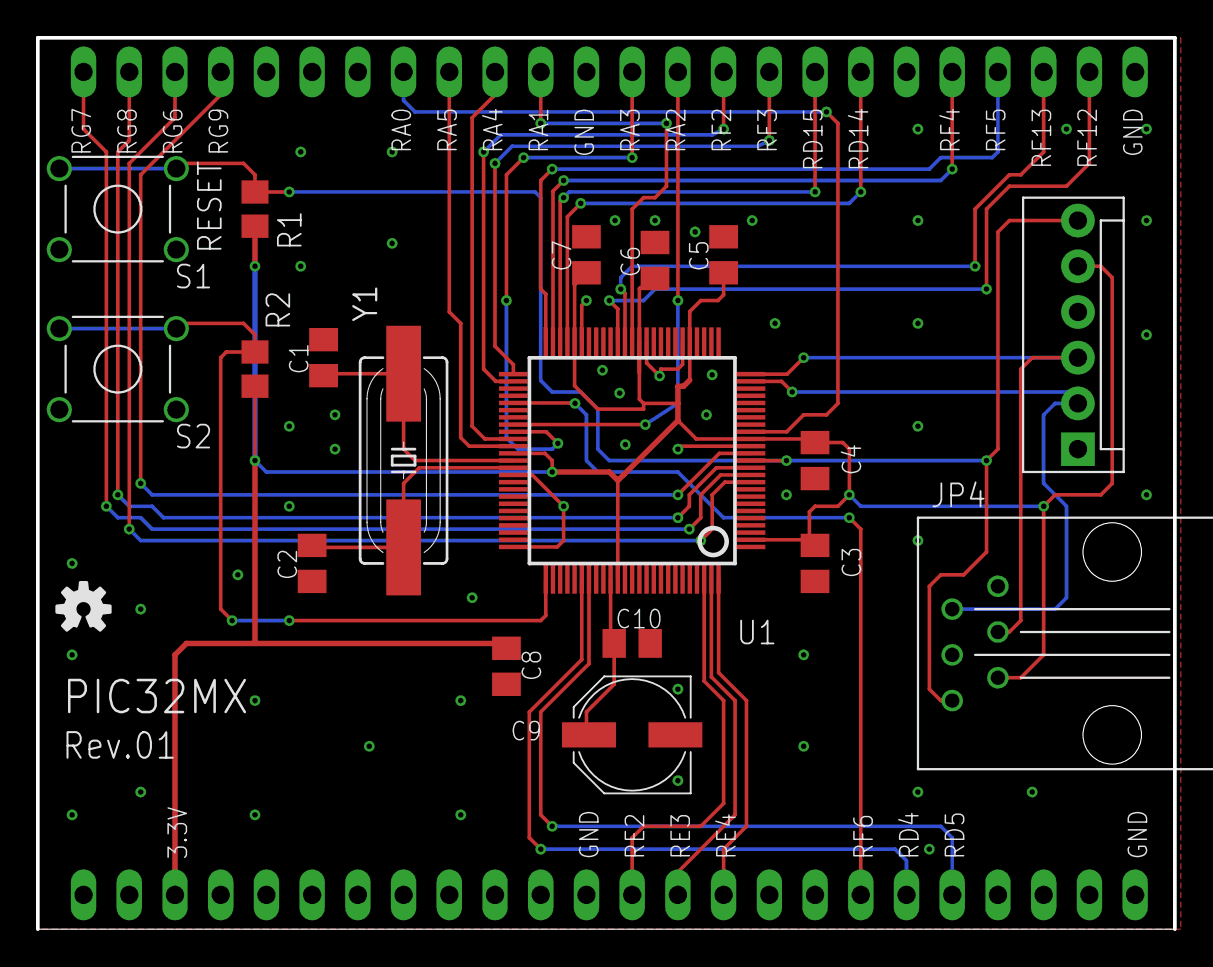
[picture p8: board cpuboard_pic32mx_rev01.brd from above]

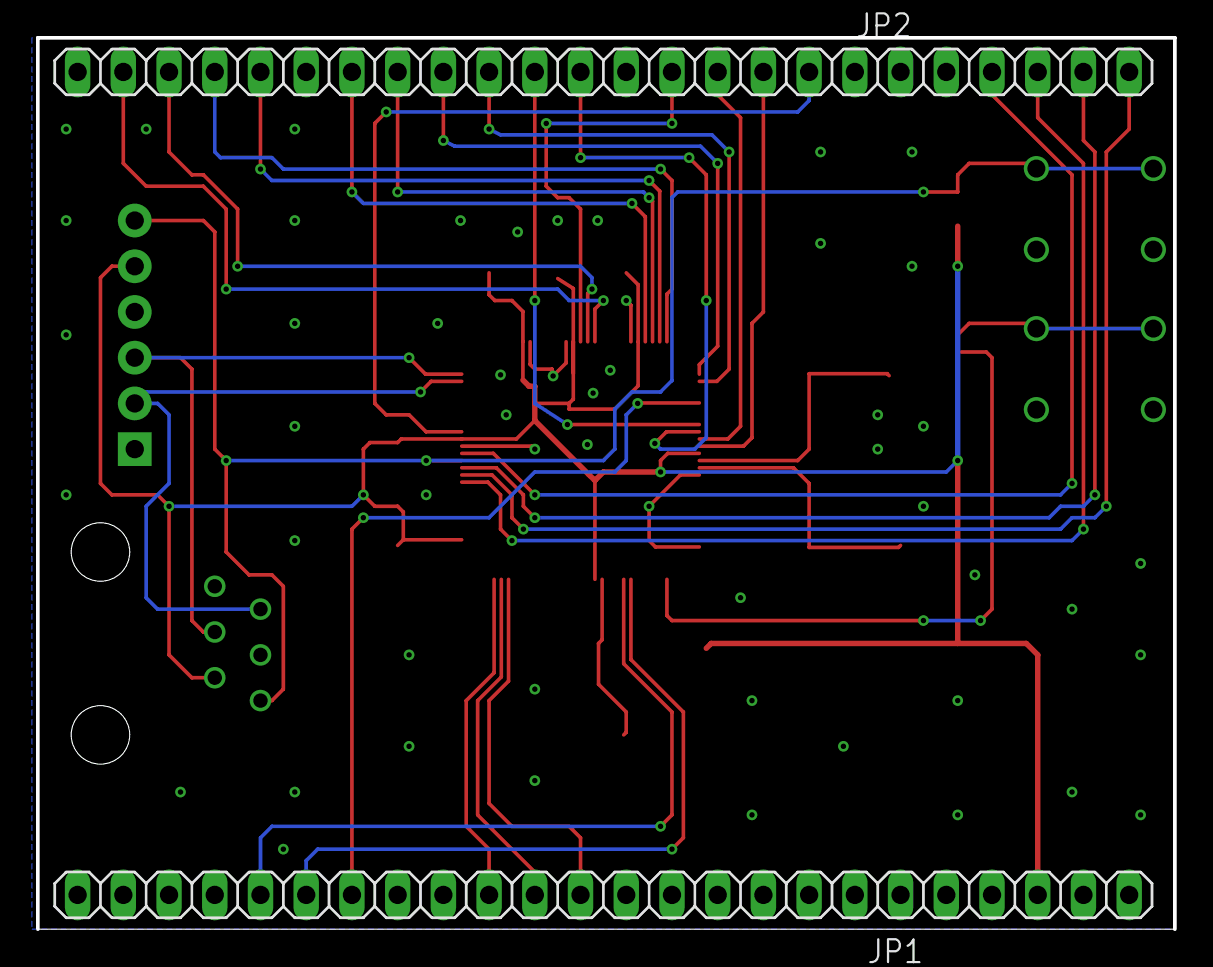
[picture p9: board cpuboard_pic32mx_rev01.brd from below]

Board: 2 copper layers, 63.2 x 49.5 mm, 21 parts (2 on the bottom side), 33 nets.

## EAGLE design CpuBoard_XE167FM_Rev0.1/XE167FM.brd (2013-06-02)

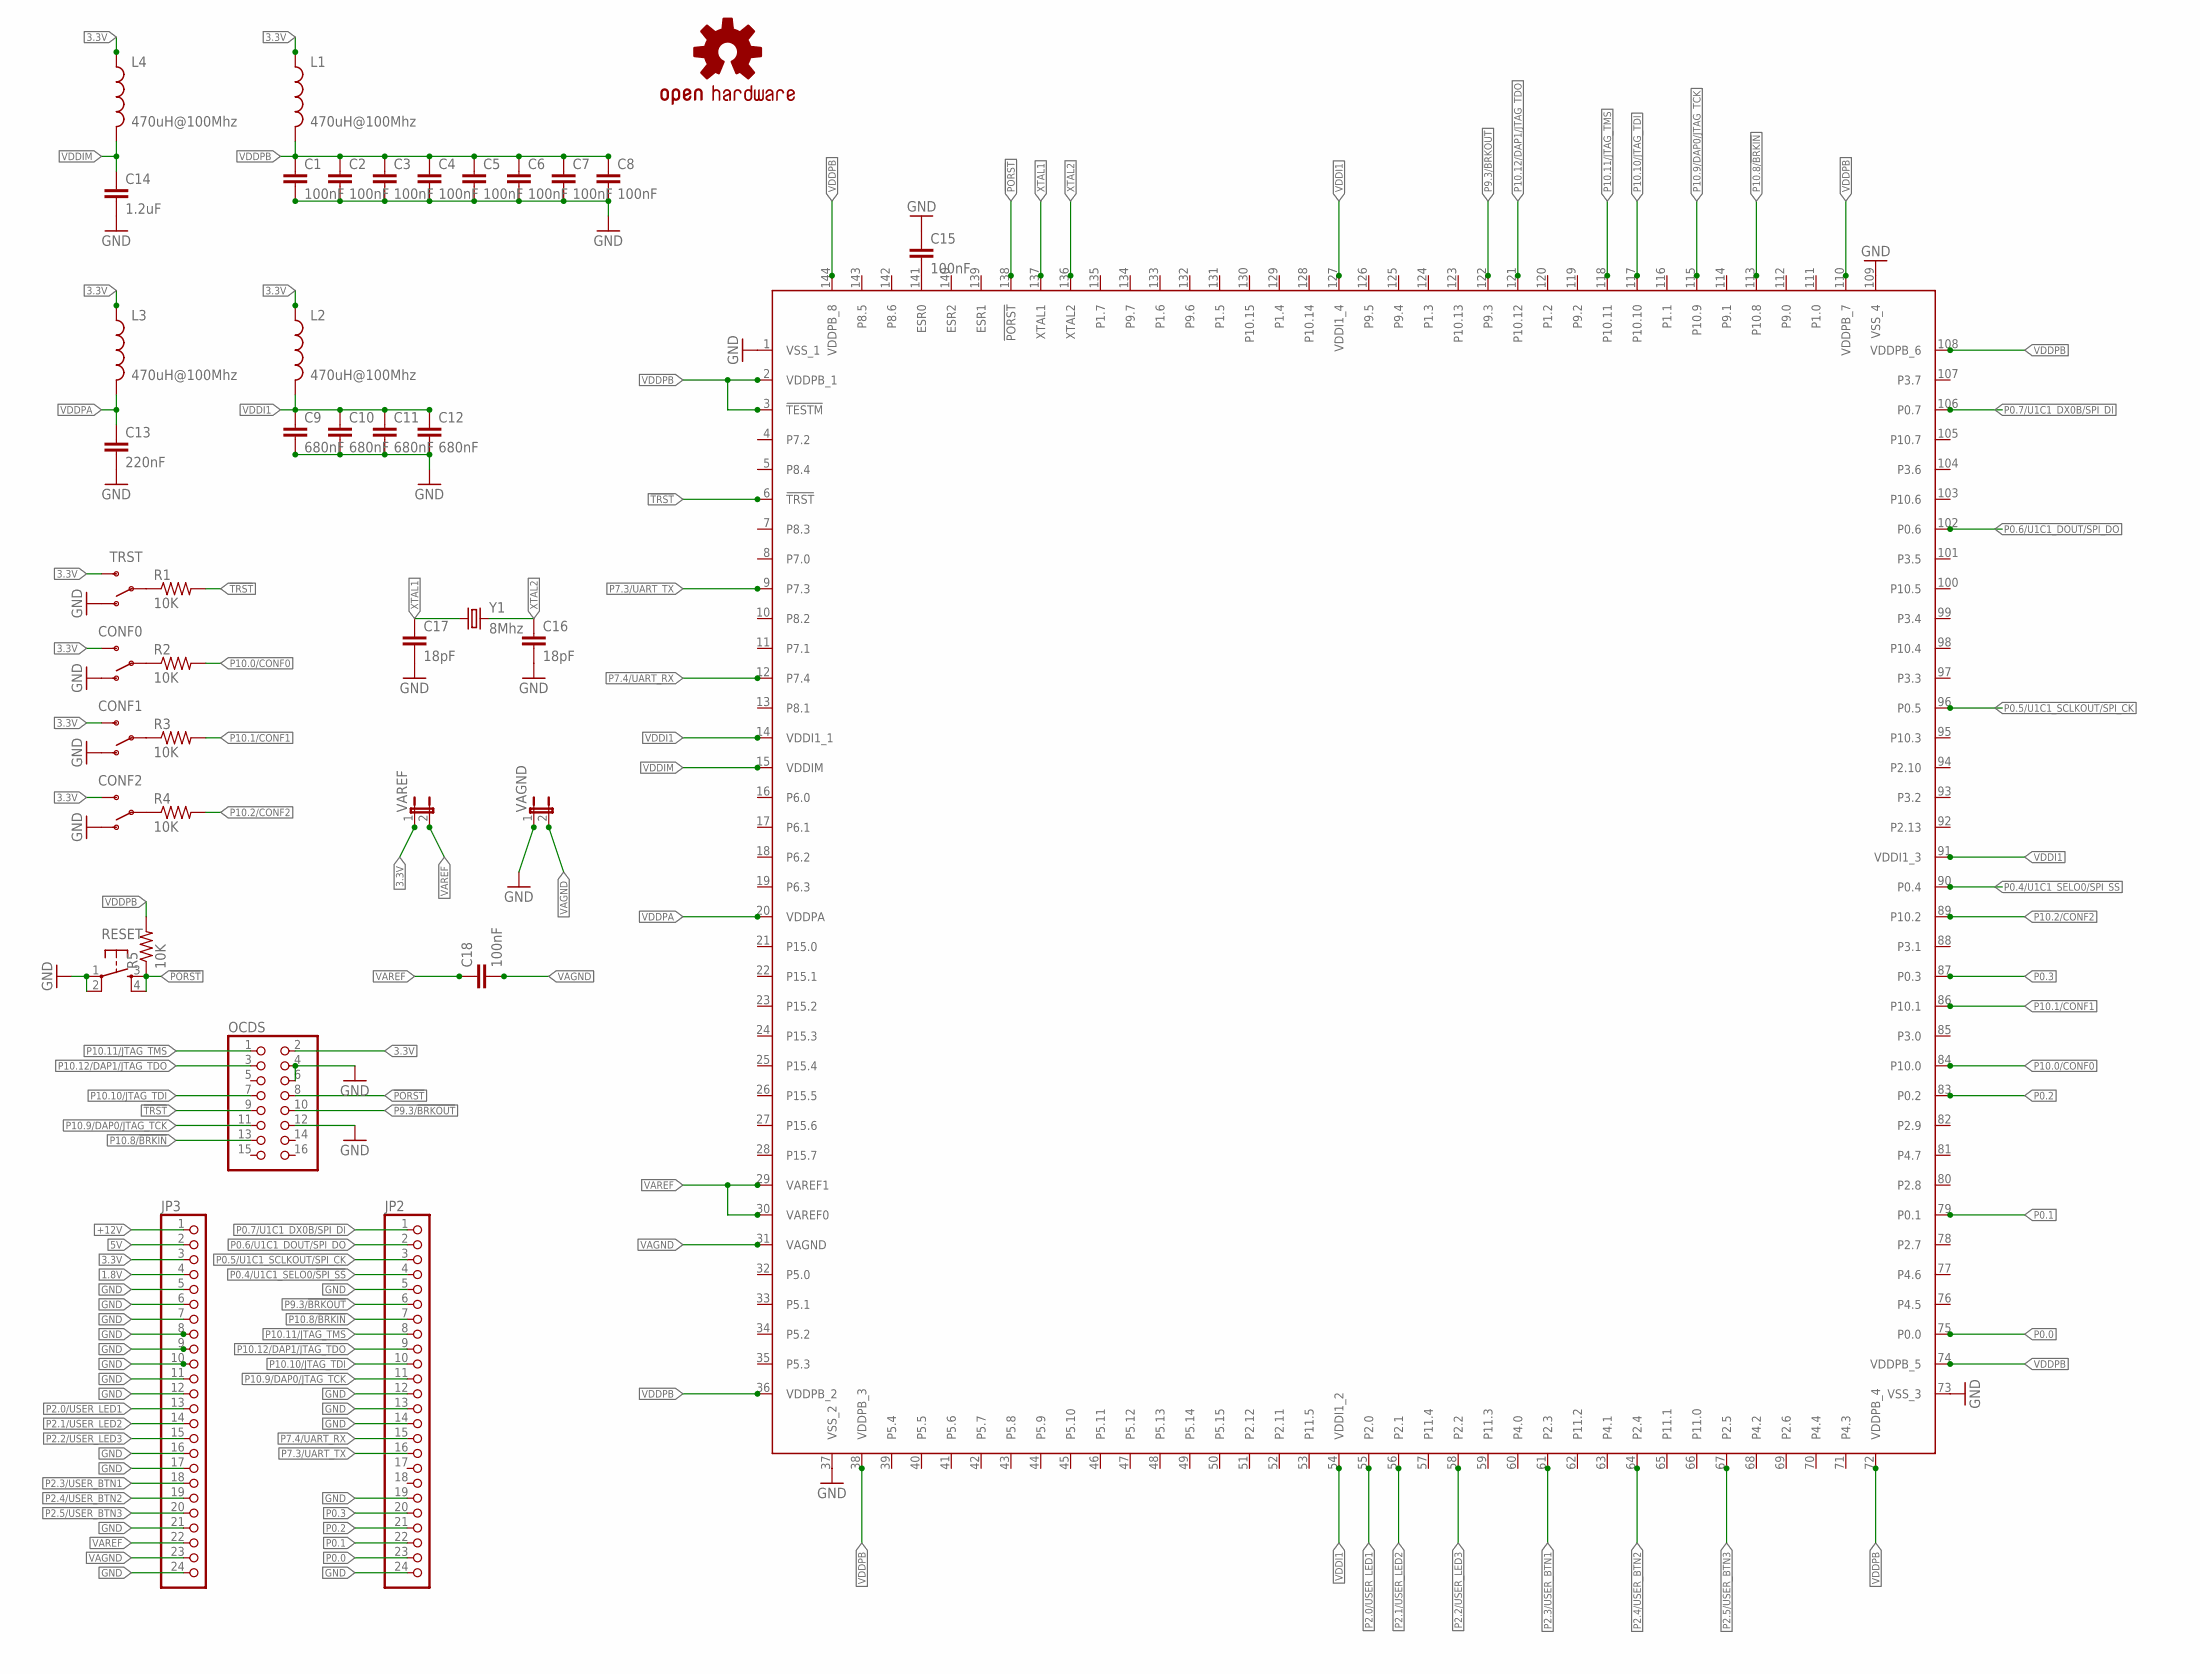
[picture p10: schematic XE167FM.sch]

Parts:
C1, C2, C3, C4, C5, C6, C7, C8, C15, C18: 100nF; 0603-CAP
C9, C10, C11, C12: 680nF; 0603-CAP
C13: 220nF; 0603-CAP
C14: 1.2uF; 0603-CAP
C16, C17: 18pF; 0603-CAP
CONF0, CONF1, CONF2: SWITCH-SPDTPTH; SWITCH-SPDT
IC1: XE167FM; LQFP144
JP2, JP3: PINHD-1X24; 1X24
L1, L2, L3, L4: 470uH@100Mhz; 0603
LOGO1: OSHW-LOGOS; OSHW-LOGO-S
OCDS: PINHD-2X8_2.54; 2X08
R1, R2, R3, R4, R5: 10K; 0603-RES
RESET: TAC_SWITCHPTH; TACTILE-PTH
TRST: SWITCH-SPDTPTH; SWITCH-SPDT
VAGND: JP1E; JP1
VAREF: JP1E; JP1
Y1: 8Mhz; HC49UP

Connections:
1.8V: JP3.4
3.3V: CONF0.3 (S), CONF1.3 (S), CONF2.3 (S), JP3.3, L1.1, L2.1, L3.1, L4.1, OCDS.2, TRST.3 (S), VAREF.1
5V: JP3.2
!PORST: IC1.138 (!PORST), OCDS.8, R5.1, RESET.3, RESET.4
!TRST: IC1.6 (!TRST), OCDS.9, R1.2
+12V: JP3.1
GND: C1.2, C2.2, C3.2, C4.2, C5.2, C6.2, C7.2, C8.2, C9.2, C10.2, C11.2, C12.2, C13.2, C14.2, C15.1, C16.2, C17.2, CONF0.1 (O), CONF1.1 (O), CONF2.1 (O), IC1.1 (VSS_1), IC1.37 (VSS_2), IC1.73 (VSS_3), IC1.109 (VSS_4), JP2.5, JP2.12, JP2.13, JP2.14, JP2.19, JP2.24, JP3.5, JP3.6, JP3.7, JP3.8, JP3.9, JP3.10, JP3.11, JP3.12, JP3.16, JP3.17, JP3.21, JP3.24, OCDS.4, OCDS.6, OCDS.12, RESET.1, RESET.2, TRST.1 (O), VAGND.1
unnamed: R1.1, TRST.2
unnamed: CONF0.2, R2.1
unnamed: CONF1.2, R3.1
unnamed: CONF2.2, R4.1
unnamed: C15.2, IC1.141 (ESR0)
P0.0: IC1.75 (P0.0), JP2.23
P0.1: IC1.79 (P0.1), JP2.22
P0.2: IC1.83 (P0.2), JP2.21
P0.3: IC1.87 (P0.3), JP2.20
P0.4/U1C1_SELO0/!SPI_SS: IC1.90 (P0.4), JP2.4
P0.5/U1C1_SCLKOUT/SPI_CK: IC1.96 (P0.5), JP2.3
P0.6/U1C1_DOUT/SPI_DO: IC1.102 (P0.6), JP2.2
P0.7/U1C1_DX0B/SPI_DI: IC1.106 (P0.7), JP2.1
P2.0/USER_LED1: IC1.55 (P2.0), JP3.13
P2.1/USER_LED2: IC1.56 (P2.1), JP3.14
P2.2/USER_LED3: IC1.58 (P2.2), JP3.15
P2.3/USER_BTN1: IC1.61 (P2.3), JP3.18
P2.4/USER_BTN2: IC1.64 (P2.4), JP3.19
P2.5/USER_BTN3: IC1.67 (P2.5), JP3.20
P7.3/UART_TX: IC1.9 (P7.3), JP2.16
P7.4/UART_RX: IC1.12 (P7.4), JP2.15
P9.3/!BRKOUT: IC1.122 (P9.3), JP2.6, OCDS.10
P10.0/CONF0: IC1.84 (P10.0), R2.2
P10.1/CONF1: IC1.86 (P10.1), R3.2
P10.2/CONF2: IC1.89 (P10.2), R4.2
P10.8/!BRKIN: IC1.113 (P10.8), JP2.7, OCDS.13
P10.9/DAP0/JTAG_TCK: IC1.115 (P10.9), JP2.11, OCDS.11
P10.10/JTAG_TDI: IC1.117 (P10.10), JP2.10, OCDS.7
P10.11/JTAG_TMS: IC1.118 (P10.11), JP2.8, OCDS.1
P10.12/DAP1/JTAG_TDO: IC1.121 (P10.12), JP2.9, OCDS.3
VAGND: C18.2, IC1.31 (VAGND), JP3.23, VAGND.2
VAREF: C18.1, IC1.29 (VAREF1), IC1.30 (VAREF0), JP3.22, VAREF.2
VDDI1: C9.1, C10.1, C11.1, C12.1, IC1.14 (VDDI1_1), IC1.54 (VDDI1_2), IC1.91 (VDDI1_3), IC1.127 (VDDI1_4), L2.2
VDDIM: C14.1, IC1.15 (VDDIM), L4.2
VDDPA: C13.1, IC1.20 (VDDPA), L3.2
VDDPB: C1.1, C2.1, C3.1, C4.1, C5.1, C6.1, C7.1, C8.1, IC1.2 (VDDPB_1), IC1.3 (!TESTM), IC1.36 (VDDPB_2), IC1.38 (VDDPB_3), IC1.72 (VDDPB_4), IC1.74 (VDDPB_5), IC1.108 (VDDPB_6), IC1.110 (VDDPB_7), IC1.144 (VDDPB_8), L1.2, R5.2
XTAL1: C17.1, IC1.137 (XTAL1), Y1.1
XTAL2: C16.1, IC1.136 (XTAL2), Y1.2

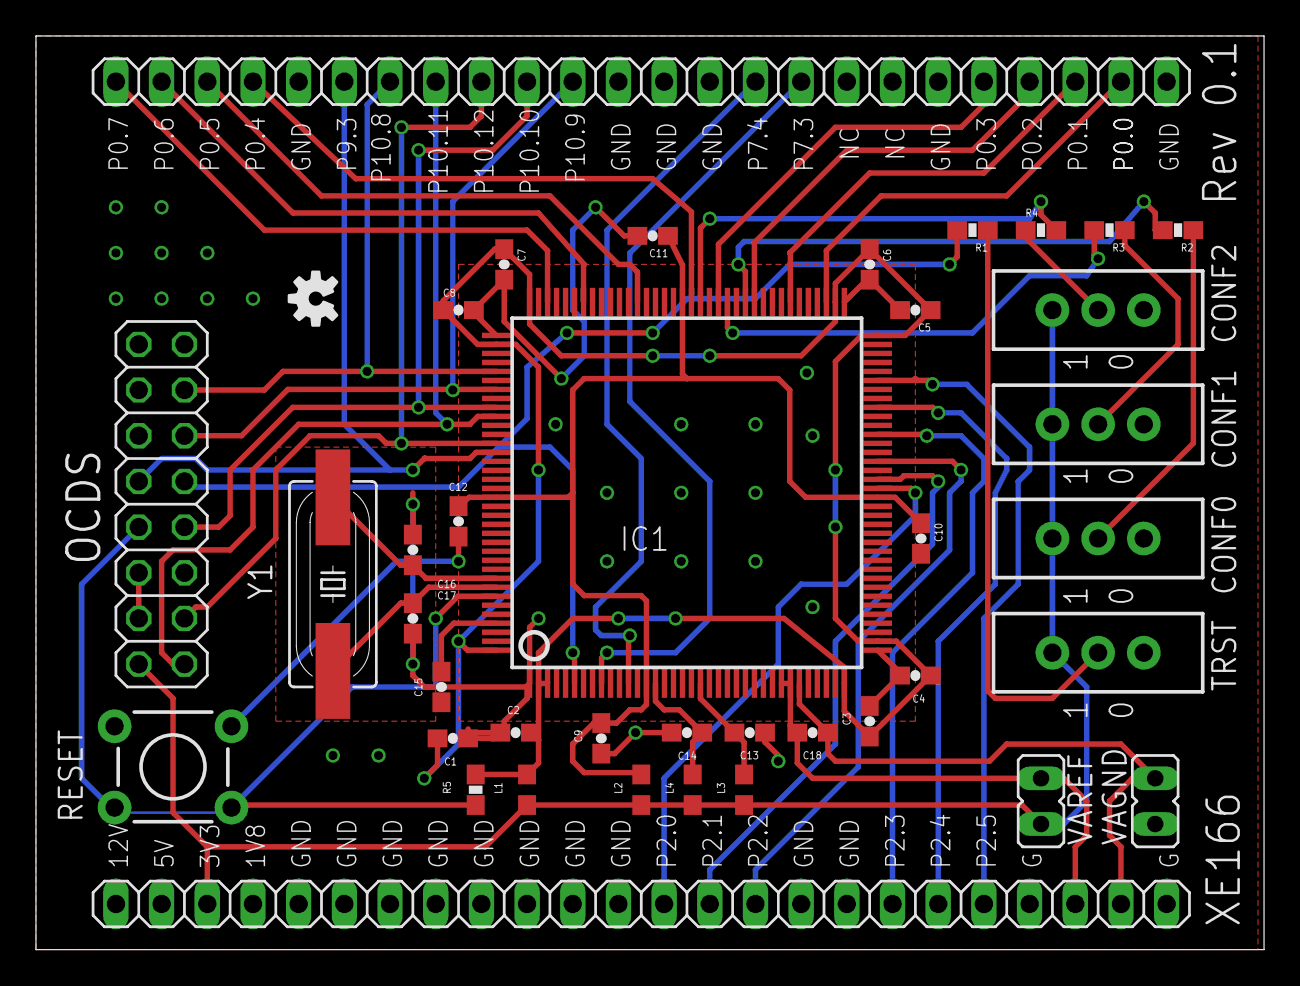
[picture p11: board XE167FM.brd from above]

Board: 2 copper layers, 68.3 x 50.8 mm, 40 parts (0 on the bottom side), 42 nets.

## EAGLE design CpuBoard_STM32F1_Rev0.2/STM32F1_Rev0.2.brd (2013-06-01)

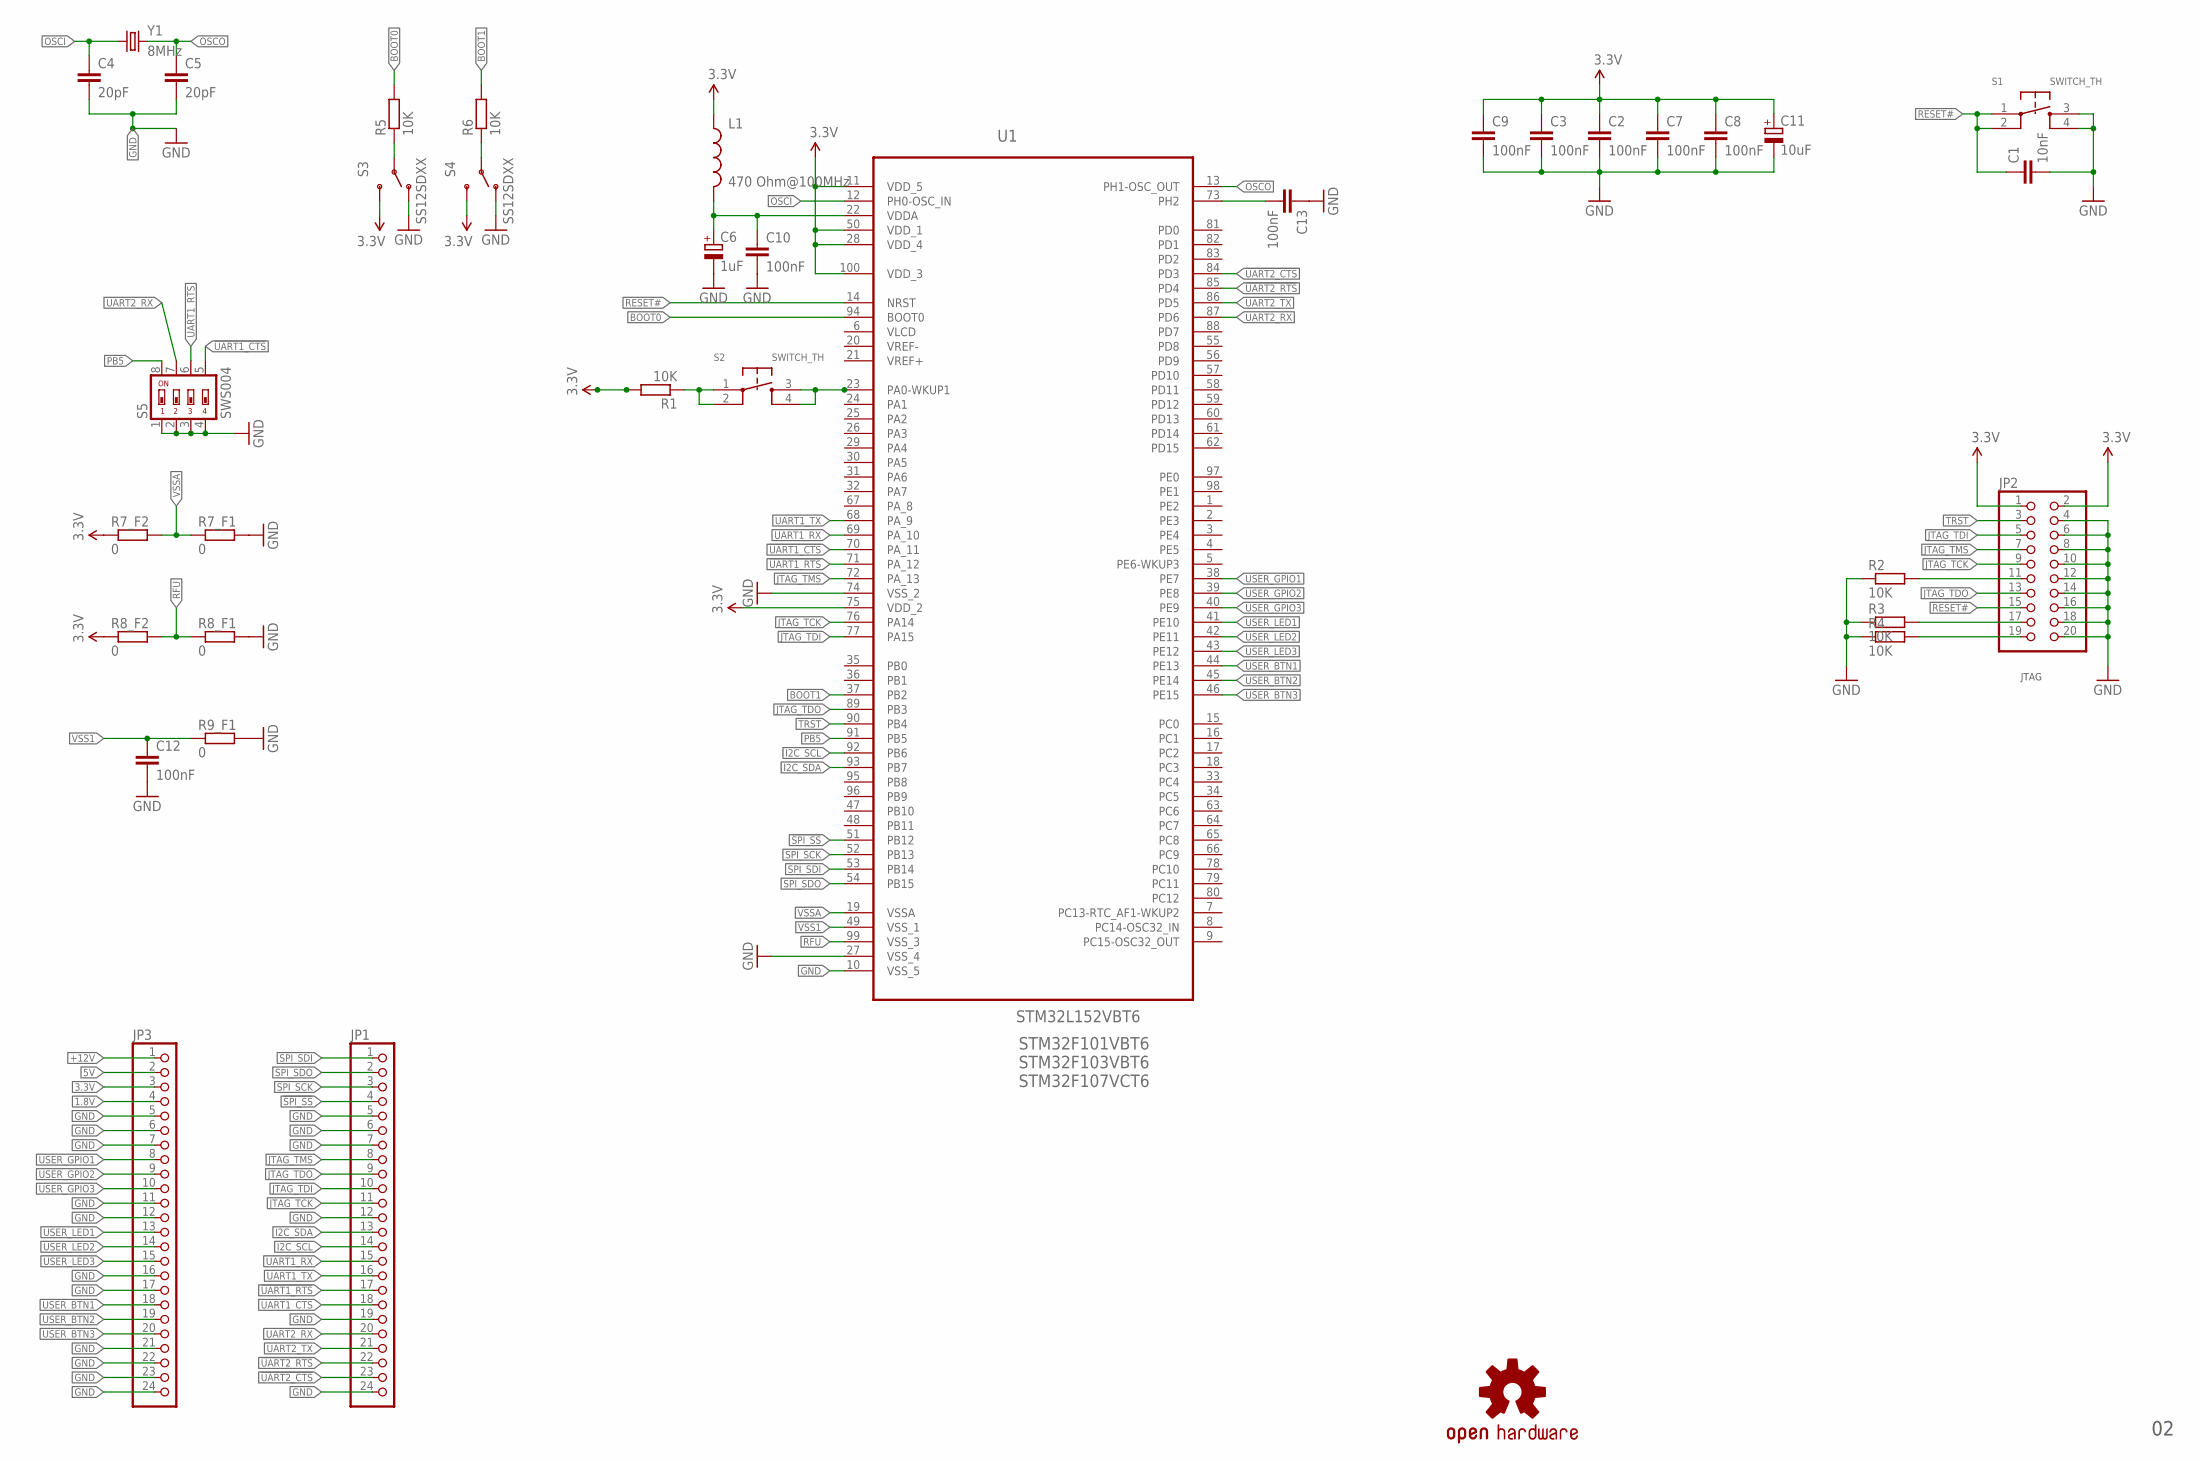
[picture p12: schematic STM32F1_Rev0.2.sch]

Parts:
C1: 10nF; C0805K
C2, C3, C7, C8, C9, C10, C12, C13: 100nF; C0805K
C4, C5: 20pF; C0805K
C6: 1uF; PANASONIC_B
C11: 10uF; PANASONIC_B
JP1, JP3: PINHD-1X24; 1X24
JP2: PINHD-2X10; 2X10
L1: 470 Ohm@100MHz; 0805
R1, R2, R3, R4, R5, R6: 10K; R0805
R7_F1, R7_F2, R8_F1, R8_F2, R9_F1: 0; R0805
S1, S2: SWITCH_TH; SWITCH_TROUGHHOLE
S3, S4: SS12SDXX
S5: SWS004; SMS-004
U1: STM32L152VBT6; QFP50P1600X1600X160-100N
U$1: OSHW-LOGOS; OSHW-LOGO-S
Y1: 8MHz; HC49UP

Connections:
1.8V: JP3.4
3.3V: C2.1, C3.1, C7.1, C8.1, C9.1, C11.+, JP2.1, JP2.2, JP3.3, L1.1, R1.2, R7_F2.1, R8_F2.1, S3.3, S4.3, U1.11 (VDD_5), U1.28 (VDD_4), U1.50 (VDD_1), U1.75 (VDD_2), U1.100 (VDD_3)
5V: JP3.2
!SPI_SS: JP1.4, U1.51 (PB12)
!UART1_CTS: JP1.18, S5.5, U1.70 (PA_11)
!UART1_RTS: JP1.17, S5.6, U1.71 (PA_12)
!UART2_CTS: JP1.23, U1.84 (PD3)
!UART2_RTS: JP1.22, U1.85 (PD4)
+12V: JP3.1
BOOT0: R5.2, U1.94 (BOOT0)
BOOT1: R6.2, U1.37 (PB2)
GND: C1.2, C2.2, C3.2, C4.2, C5.2, C6.-, C7.2, C8.2, C9.2, C10.2, C11.-, C12.2, C13.1, JP1.5, JP1.6, JP1.7, JP1.12, JP1.19, JP1.24, JP2.4, JP2.6, JP2.8, JP2.10, JP2.12, JP2.14, JP2.16, JP2.18, JP2.20, JP3.5, JP3.6, JP3.7, JP3.11, JP3.12, JP3.16, JP3.17, JP3.21, JP3.22, JP3.23, JP3.24, R2.1, R3.1, R4.1, R7_F1.2, R8_F1.2, R9_F1.2, S1.3, S1.4, S3.1, S4.1, S5.1, S5.2, S5.3, S5.4, U1.10 (VSS_5), U1.27 (VSS_4), U1.74 (VSS_2)
I2C_SCL: JP1.14, U1.92 (PB6)
I2C_SDA: JP1.13, U1.93 (PB7)
JTAG_TCK: JP1.11, JP2.9, U1.76 (PA14)
JTAG_TDI: JP1.10, JP2.5, U1.77 (PA15)
JTAG_TDO: JP1.9, JP2.13, U1.89 (PB3)
JTAG_TMS: JP1.8, JP2.7, U1.72 (PA_13)
unnamed: C13.2, U1.73 (PH2)
unnamed: C6.+, C10.1, L1.2, U1.22 (VDDA)
unnamed: R1.1, S2.1, S2.2
unnamed: R5.1, S3.2
unnamed: R6.1, S4.2
unnamed: JP2.11, R2.2
unnamed: JP2.17, R3.2
unnamed: JP2.19, R4.2
OSCI: C4.1, U1.12 (PH0-OSC_IN), Y1.1
OSCO: C5.1, U1.13 (PH1-OSC_OUT), Y1.2
PA0: S2.3, S2.4, U1.23 (PA0-WKUP1)
PB5: S5.8, U1.91 (PB5)
RESET#: C1.1, JP2.15, S1.1, S1.2, U1.14 (NRST)
RFU: R8_F1.1, R8_F2.2, U1.99 (VSS_3)
SPI_SCK: JP1.3, U1.52 (PB13)
SPI_SDI: JP1.1, U1.53 (PB14)
SPI_SDO: JP1.2, U1.54 (PB15)
TRST: JP2.3, U1.90 (PB4)
UART1_RX: JP1.15, U1.69 (PA_10)
UART1_TX: JP1.16, U1.68 (PA_9)
UART2_RX: JP1.20, S5.7, U1.87 (PD6)
UART2_TX: JP1.21, U1.86 (PD5)
USER_BTN1: JP3.18, U1.44 (PE13)
USER_BTN2: JP3.19, U1.45 (PE14)
USER_BTN3: JP3.20, U1.46 (PE15)
USER_GPIO1: JP3.8, U1.38 (PE7)
USER_GPIO2: JP3.9, U1.39 (PE8)
USER_GPIO3: JP3.10, U1.40 (PE9)
USER_LED1: JP3.13, U1.41 (PE10)
USER_LED2: JP3.14, U1.42 (PE11)
USER_LED3: JP3.15, U1.43 (PE12)
VLCD: U1.6 (VLCD)
VSS1: C12.1, R9_F1.1, U1.49 (VSS_1)
VSSA: R7_F1.1, R7_F2.2, U1.19 (VSSA)

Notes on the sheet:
JTAG
STM32F101VBT6 STM32F103VBT6 STM32F107VCT6



Board: 2 copper layers, 63.2 x 50.8 mm, 36 parts (2 on the bottom side), 48 nets.

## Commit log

2013-06-01 Project start
    CpuBoards for STM32F1xx/L1xx/F2xx and Infineon XE167FM
    [STM32F1_Rev0.2.brd, STM32F1_Rev02.sch, STM32F1_Rev02_BOM.csv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]
2013-06-01 Files renamed for consistency
    [STM32F1_Rev0.2.sch, STM32F1_Rev0.2_BOM.csv]
2013-06-01 Visible bottom layer for STM32 board
    [STM32F1_Rev0.2.brd]
2013-06-01 Missing GND pin description
    [XE167FM.brd, XE167FM.sch]
2013-06-01 OSHW logo rotated
    [XE167FM.brd]
2013-06-02 Texts position slightly corrected
    [XE167FM.brd]
2013-06-24 Added designs made by Claudiu Covaci
    Added BaseBoard 0.1 and CPUBoard_PIC 0.1
    [baseboard_bom_rev_01.xlsx, baseboard_rev_01.brd, baseboard_rev_01.sch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]
2013-07-01 Base Board revision 0.2
    Added schematics of early version of BB 0.2
    [baseboard_rev_0.2.brd, baseboard_rev_0.2.sch]
2013-07-03 Added shunt resistor for current measurement
    In case of no ammeter
    [baseboard_0.2.brd, baseboard_0.2.sch]

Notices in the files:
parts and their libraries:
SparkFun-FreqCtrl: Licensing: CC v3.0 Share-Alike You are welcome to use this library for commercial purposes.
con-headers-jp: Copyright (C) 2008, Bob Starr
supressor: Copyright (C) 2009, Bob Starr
